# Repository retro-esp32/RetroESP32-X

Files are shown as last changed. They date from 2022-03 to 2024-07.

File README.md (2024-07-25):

# Introducing the Retro ESP32 *X*

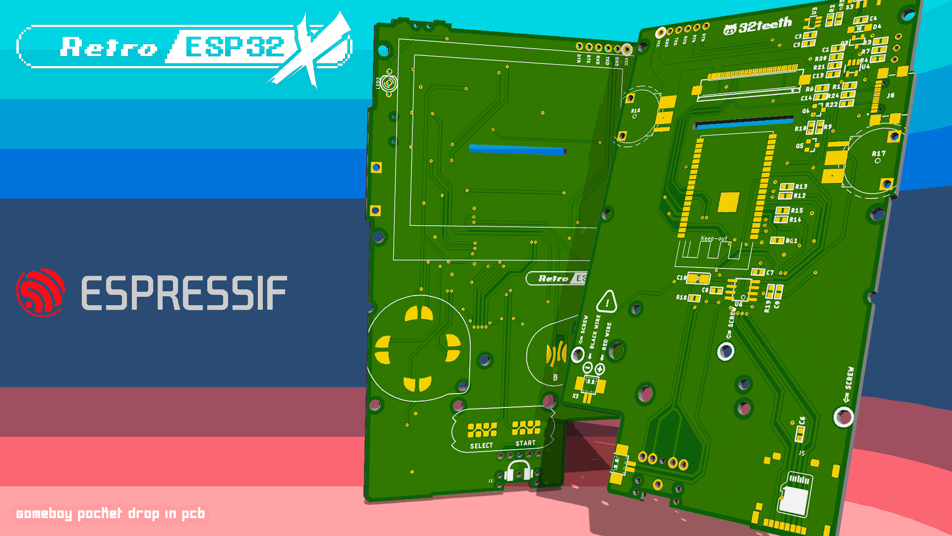
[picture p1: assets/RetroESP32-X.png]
Retro ESP32

> Gameboy Pocket Drop In PCB

We're thrilled to unveil the latest and greatest iteration of our beloved Retro ESP32 - the Retro ESP32 X! 🚀🕹️

**Retro ESP32 X** is certified unde Open Source Hardware as OSHWA UID [CA000030](https://certification.oshwa.org/ca000030.html) with CC-BY-SA-4.0 licensing

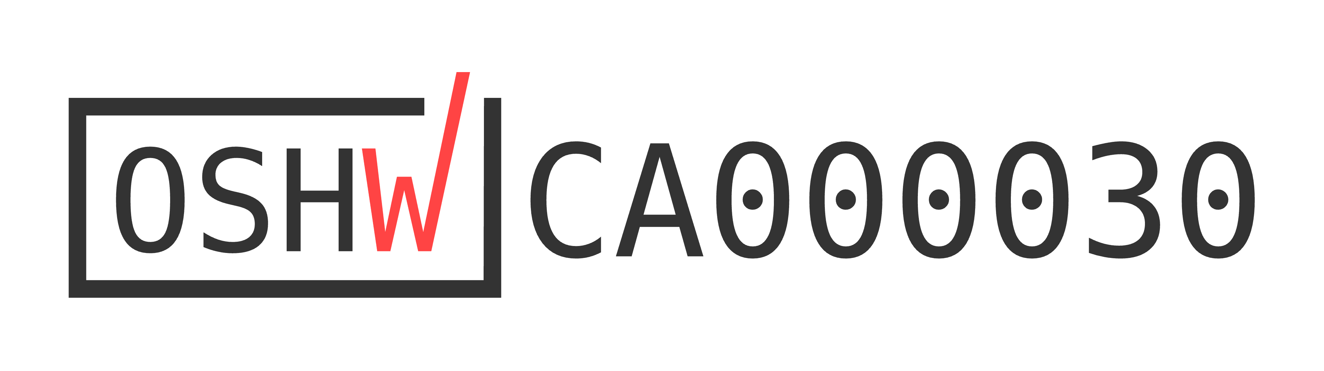
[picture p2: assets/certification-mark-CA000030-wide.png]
Open Source


## What's Public

- [x] PCB
- [x] Schematic
- [x] BOM
- [x] Gerber
- [x] DXF

## Updated Features

- [x] 2.6" ILI9342C SPI ISP
- [x] FPC Ribbon Connector
- [x] USB C (Charge Only)
- [x] Serial Pin Breakout

## Images

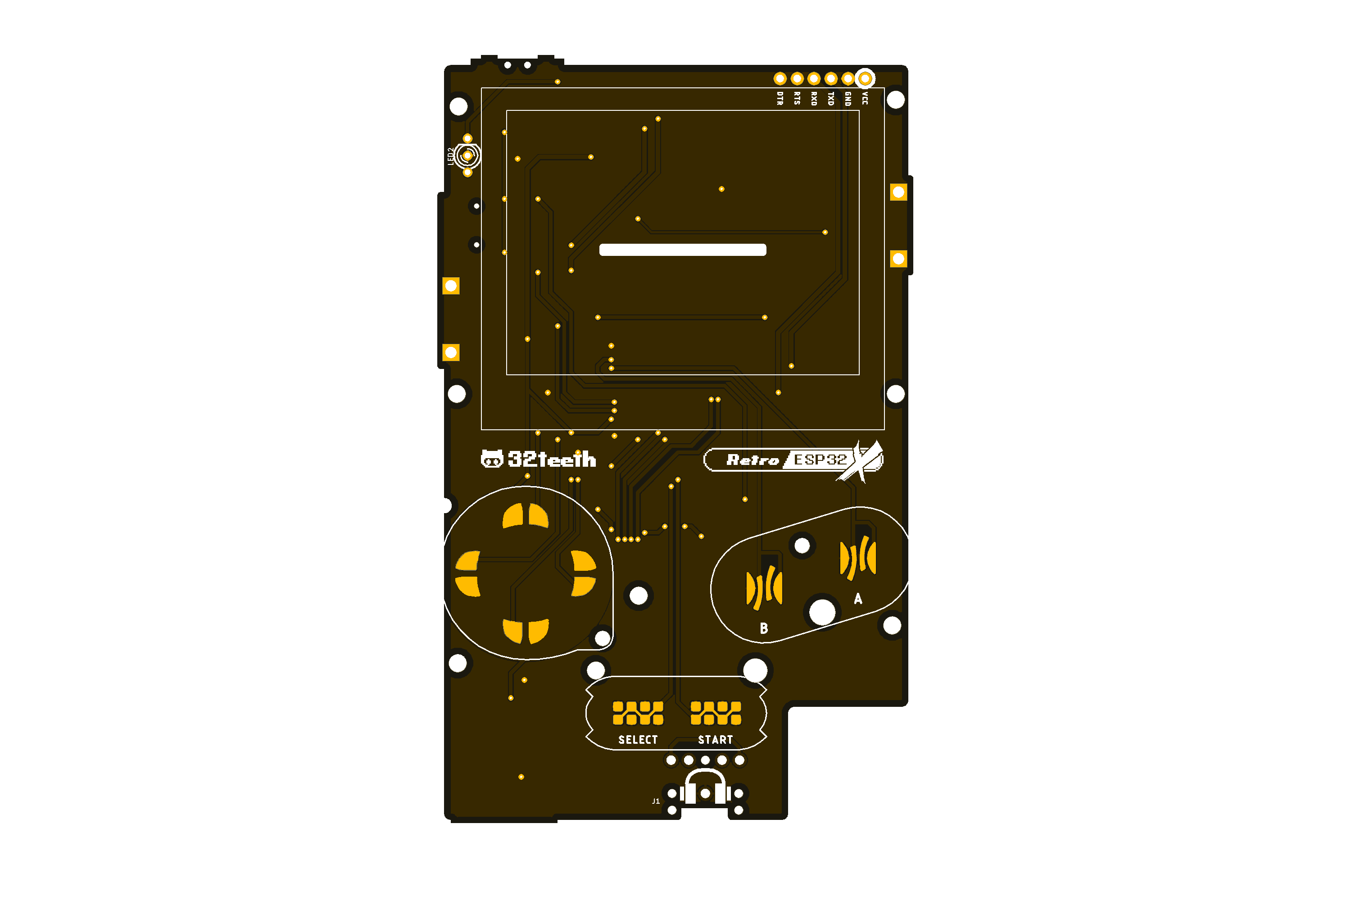
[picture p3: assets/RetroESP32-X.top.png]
Retro ESP32
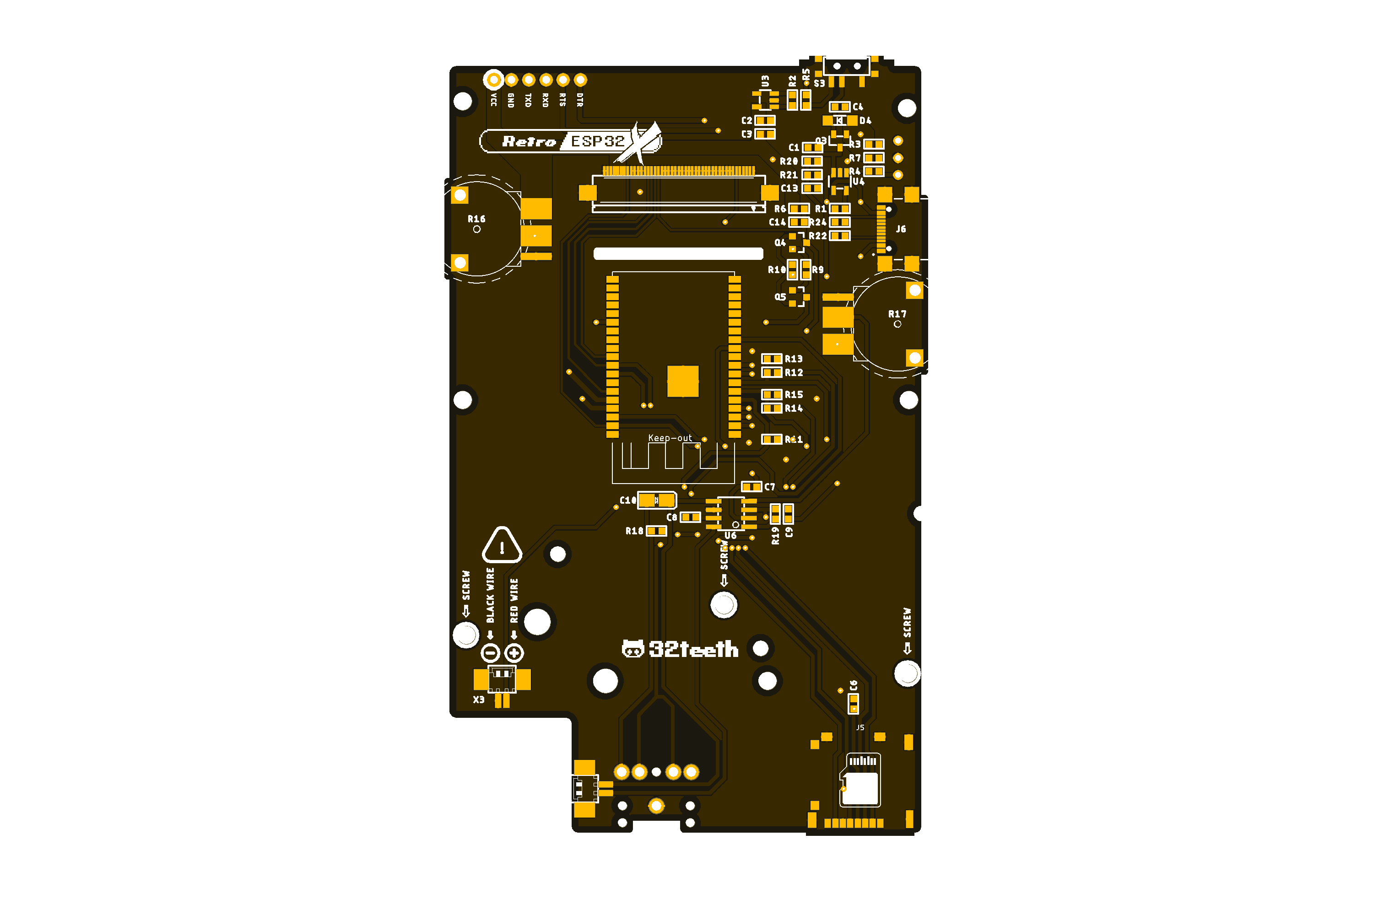
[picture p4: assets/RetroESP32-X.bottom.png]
Retro ESP32
|   |  |
| ---- | --- |
| Top  | Bottom |

## Authors

* **Eugene Yevhen Andruszczenko** - *Initial and Ongoing Work* - [32teeth](https://github.com/32teeth)

### License

This project is licensed under the Creative Commons Attribution Share Alike 4.0 International - see the [LICENSE.md](LICENSE.md) file for details

## Support
> Although we do this for 💕 of 🕹️<br/>
> **We Also Like Coffee!** <br/>
> *Please Consider Supporting* <br/>

Did you know, you can support us in a few way? We offer multiple sposorship tiers, with different rewards!

Take a *look*.
See what *fits*.

 Support (https://github.com/sponsors/retro-esp32)

**Thank You**

-----

**📢 Important Update:**
Please note that the original Retro ESP32 is now deprecated and is no longer supported. But fret not, because the all-new Retro ESP32 X is here to take your gaming experience to new heights! 📈✨

***The Retro ESP32 X uses the firmware from [Ducalex - Retro Go](https://github.com/ducalex/retro-go)***

Link to the Origina Rettro ESP32 Firmware Repo: [Check it out here!](https://github.com/retro-esp32/RetroESP32)

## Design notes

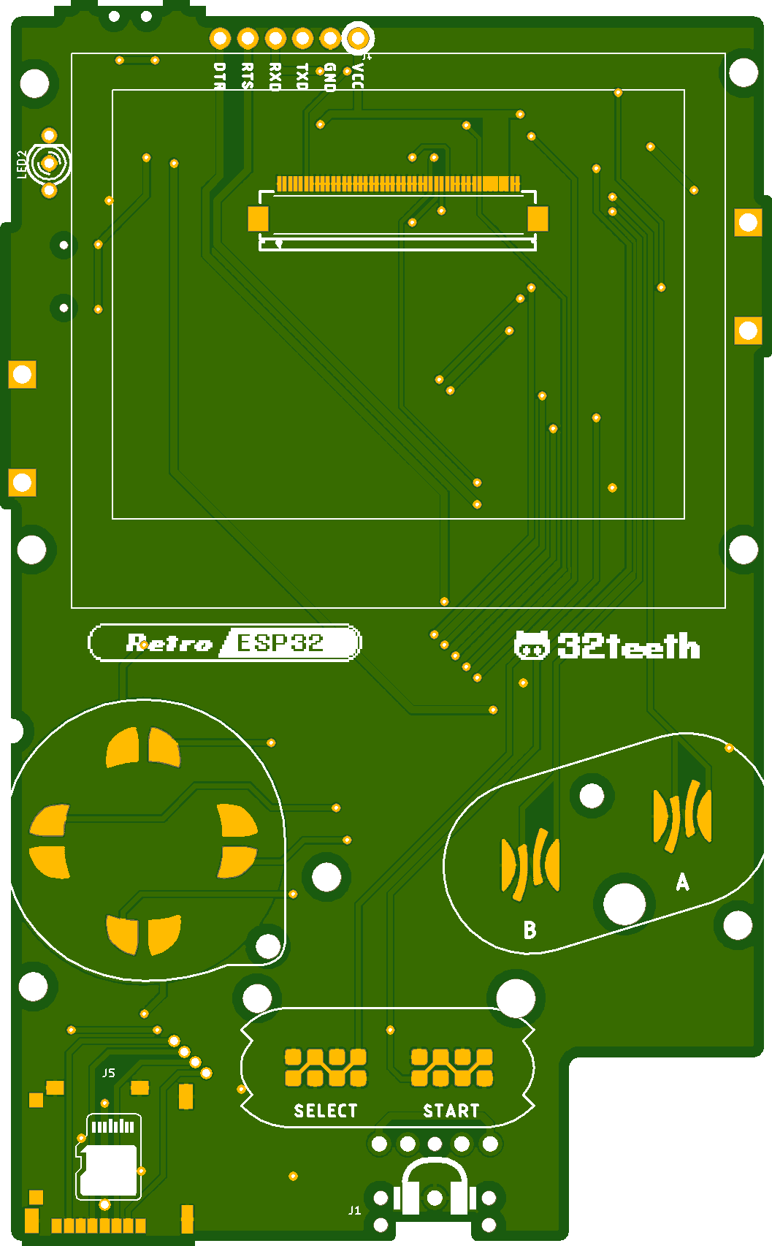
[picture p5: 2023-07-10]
assets/RetroESP32.serial.top.png

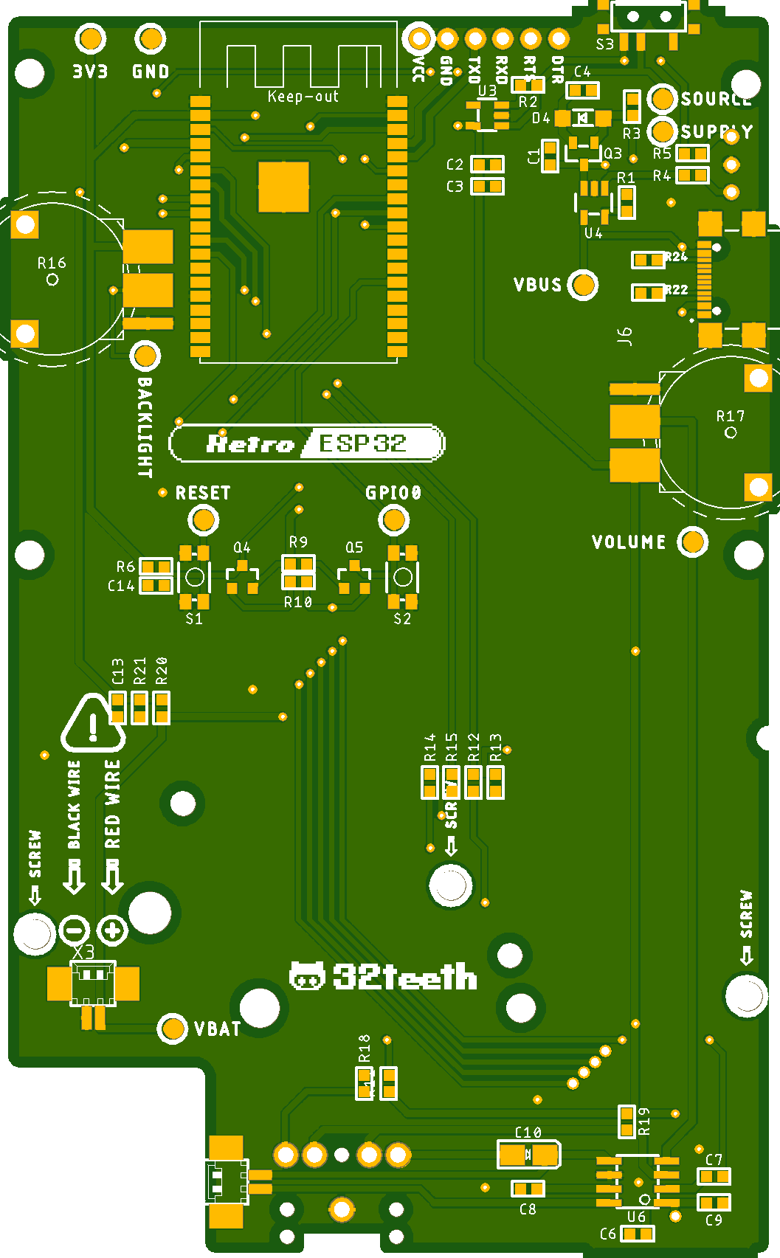
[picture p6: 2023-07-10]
assets/RetroESP32.serial.bottom.png

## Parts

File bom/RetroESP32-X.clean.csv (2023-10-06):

Qty | Parts | Value | MPN | Package | Device
1 | J4 |  |  | 1X06_NO_SILK | CONN_06NO_SILK_NO_POP
1 | R7 | 0 | ERJ-3GEY0R00V | 0603-MINI | RESISTOR0603MINI
1 | C13 | 0.1uF | CL10B104KB8NNNC | 0603-MINI-CAP | CAP_CERAMIC
5 | R2, R3, R19, R20, R21 | 100K | ERJ-PA3J104V | 0603-MINI | RESISTOR0603MINI
1 | C10 | 100uF | F930J107KAA | EIA3216-18/A-W | CAP_TANTALUMA/3216_WAVE
8 | R6, R9, R10, R11, R12, R13, R14, R15 | 10K | ERJ-PA3J103V | 0603-MINI | RESISTOR0603MINI
4 | C1, C2, C4, C6 | 10uF | CL10A106MP8NNNC | 0603-MINI-CAP | CAP_CERAMIC
1 | R18 | 150 Ohm | ERJ-PA3J151V | 0603-MINI | RESISTOR0603MINI
2 | R1, R5 | 1K | ERJ-PA3J102V | 0603-MINI | RESISTOR0603MINI
4 | C3, C8, C9, C14 | 1uF | CL10A105KP8NNNC | 0603-MINI-CAP | CAP_CERAMIC
1 | C7 | 220pF | CL10C221JB8NNNC | 0603-MINI-CAP | CAP_CERAMIC
2 | R16, R17 | 27k |  | THUMBWHEEL | THUMBWHEEL
1 | R4 | 470 | ERJ-PA3J471V | 0603-MINI | RESISTOR0603MINI
2 | R22, R24 | 5.1K | ERJ-PA3F5101V | 0603-MINI | RESISTOR0603MINI
1 | J5 | 503182-1852_503182-1852 | 5031821852 | 503182-1852_MOLEX_503182-1852 | 503182-1852_503182-1852
2 | X2, X3 | 53261-02 | 532614002 | 53261-02 | 53261-02
1 | J1 | AUDIO_JACK_3.5MM_KIT | SJ1-3525NG-GR | AUDIO-JACK-KIT | AUDIO_JACK_3.5MM_KIT
2 | SELECT, START | BUTTON_START+SELECT |  | START+SELECT-STANDARD | BUTTON_START+SELECT
1 | Q3 | DMG3415U-7 | DMG3415U-7 | SOT23-R | MOSFET-P
1 | U1 | ESP32-WROVER | ESP32-WROVER (16MB) | ESP32-WROVER_ESP32-WROVER | ESP32-WROVER
1 | U$11 |  | 541044531
1 | LED2 | LED_L-115WEGW-CA | SSL-LX3059IGW | LED_DUOLED-A-3MM | LED_L-115WEGW-CA
1 | U6 | LM4875 | LM4875MX/NOPB | SOIC8 | LM4875
1 | D4 | MBR120 | MBR120LSFT1G | SOD-123 | DIODE-SCHOTTKYSOD-123
1 | U4 | MCP73832T-2ACI/OT | MCP73832T-2ACI/OT | SOT23-5-1 | MCP73831/2
1 | S3 | POWER-SWITCH | MA12RTR | RETIRED_KPS-1290 | POWER-SWITCH
1 | J6 | USB4110-GF-A_REVB | USB4110-GF-A | GCT_USB4110-GF-A_REVB | USB4110-GF-A_REVB
1 | U3 | XC6210B332MR-G | XC6210B332MR-G | SOT23-5 | AP2112-3.3
2 | Q4, Q5 | mmbt2222 | MMBT2222A-7-F | SOT23-3 | TRANSISTOR_NPNSOT23-3

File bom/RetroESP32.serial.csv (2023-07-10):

Qty | Designator | MPN | Purchase Link
1 | J1 | SJ1-3525NG-GR | https://www.digikey.com/en/products/detail/cui-devices/SJ1-3525NG-GR/2295990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
1 | C13 | CL10B104KB8NNNC | https://www.digikey.com/en/products/detail/samsung-electro-mechanics/CL10B104KB8NNNC/3886658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
4 | C1, C2, C4, C6 | CL10A106MP8NNNC | https://www.digikey.com/en/products/detail/samsung-electro-mechanics/CL10A106MP8NNNC/3887529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
4 | C3, C8, C9, C14 | CL10A105KP8NNNC | https://www.digikey.com/en/products/detail/samsung-electro-mechanics/CL10A105KP8NNNC/3886840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
1 | C7 | CL10C221JB8NNNC | https://www.digikey.com/en/products/detail/samsung-electro-mechanics/CL10C221JB8NNNC/3886706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
1 | J5 | 5031821852 | https://www.digikey.com/en/products/detail/molex/5031821852/4693482?s=N4IgTCBcDaIKwAYDMBGAHGdcIF0C%2BQA
1 | J6 | USB4110-GF-A | https://www.digikey.com/en/products/detail/gct/USB4110-GF-A/10384547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
1 | U4 | MCP73832T-2ACI/OT | https://www.digikey.com/en/products/detail/microchip-technology/MCP73832T-2ACI-OT/1223142
2 | S1, S2 | KMR221GLFS | https://www.digikey.com/en/products/detail/c-k/KMR221GLFS/550472?s=N4IgTCBcDaINIFkBKYwEYDiAZAYgZRAF0BfIA
1 | Q3 | DMG3415U-7 | https://www.digikey.com/en/products/detail/diodes-incorporated/DMG3415U-7/2052768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
2 | R1, R5 | ERJ-PA3J152V | https://www.digikey.com/en/products/detail/panasonic-electronic-components/ERJ-PA3J152V/5035991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
5 | R2, R3, R19, R20, R21 | ERJ-PA3J104V | https://www.digikey.com/en/products/detail/panasonic-electronic-components/ERJ-PA3J104V/5035972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
8 | R6, R9, R10, R11, R12, R13, R14, R15 | ERJ-PA3J103V | https://www.digikey.com/en/products/detail/panasonic-electronic-components/ERJ-PA3J103V/5035971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
1 | R18 | ERJ-PA3J151V | https://www.digikey.com/en/products/detail/panasonic-electronic-components/ERJ-PA3J151V/5035990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
1 | R4 | ERJ-PA3J471V | https://www.digikey.com/en/products/detail/panasonic-electronic-components/ERJ-PA3J471V/5036065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
2 | R22, R24 | ERJ-PA3F5101V | https://www.digikey.com/en/products/detail/panasonic-electronic-components/ERJ-PA3F5101V/5035934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
1 | U3 | XC6210B332MR-G | https://www.digikey.com/en/products/detail/torex-semiconductor-ltd/XC6210B332MR-G/2138119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
1 | S3 | MA12RTR | https://www.digikey.com/en/products/detail/apem-inc/MA12RTR/1795601?s=N4IgTCBcDaILIEECMYBKAVVIC6BfIA
1 | LED2 | SSL-LX3059IGW | https://www.digikey.com/en/products/detail/lumex-opto-components-inc/SSL-LX3059IGW/242268
1 | C10 | F930J107KAA | https://www.digikey.com/en/products/detail/kyocera-avx/F930J107KAA/4005275
2 | Q4, Q5 | MMBT2222A-7-F | https://www.digikey.com/en/products/detail/diodes-incorporated/MMBT2222A-7-F/814503
1 | U1 | ESP32-WROVER (16MB) | https://www.digikey.com/en/products/filter/rf-transceiver-modules-and-modems/872
1 | U$11 | 541324562 | https://www.digikey.com/en/products/detail/molex/0541324562/3197010
1 | U6 | LM4875MX/NOPB | https://www.digikey.com/en/products/detail/texas-instruments/LM4875MX-NOPB/1871686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
1 | D4 | MBR120LSFT1G | https://www.digikey.com/en/products/detail/onsemi/MBR120LSFT1G/1748986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
2 | X2, X3 | 53261-02 | 0532614002 | https://www.digikey.ca/en/products/detail/molex/0532614002/15622958
1 | N/A - This is the LCD itself | ET026LQTM008 | https://www.alibaba.com/product-detail/Support-Small-Quantity-2-6-inch_1600609986142.htmlgit

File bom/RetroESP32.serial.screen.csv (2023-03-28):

Qty | Designator | MPN | Purchase Link
1 | U$11 | 541324562 | https://www.digikey.com/en/products/detail/molex/0541324562/3197010

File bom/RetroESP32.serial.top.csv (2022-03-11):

Qty | Designator | MPN | Purchase Link
1 | J5 | 5031821852 | https://www.digikey.com/en/products/detail/molex/5031821852/4693482?s=N4IgTCBcDaIKwAYDMBGAHGdcIF0C%2BQA
1 | U$11 | 541324562 | https://www.digikey.com/en/products/detail/molex/0541324562/3197010

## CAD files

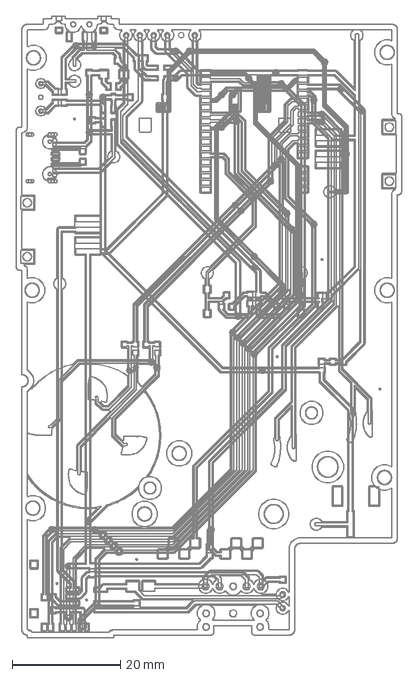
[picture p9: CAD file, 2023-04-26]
dxf/RetroESP32.serial 2.dxf
71.2 x 115.0 mm

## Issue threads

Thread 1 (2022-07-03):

Will there be any issue if using ili9341 display driver insted of ili9342?

rohitsam, 2022-07-03:
I want to work on this project, but am unable to find ili9342-based displays here in India.
I found a couple of displays that are
[ili9341 based](https://robu.in/product/2-2-inch-240320-lcd-color-screen-tft-spi-serial-interface-module-compatible-with-5110/) could anyone please tell me if these can work?

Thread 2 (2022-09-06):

Charger chip

mikeinkl1, 2022-09-06:
Gren led doesnt come on. The issue is probably that
U4 should be MCP73831 not MCP73832.
Otherwise great little project.

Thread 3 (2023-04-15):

Thumbwheel link

advtechsol, 2023-04-15:
Do you have a link for the thumbwheel component?

32teeth, 2023-04-24:
This is the one we use
[Gameboy Pocket Pot Switch](https://www.aliexpress.us/item/3256804826762559.html?gatewayAdapt=glo2usa4itemAdapt&_randl_shipto=US)

I will add them to the BOM

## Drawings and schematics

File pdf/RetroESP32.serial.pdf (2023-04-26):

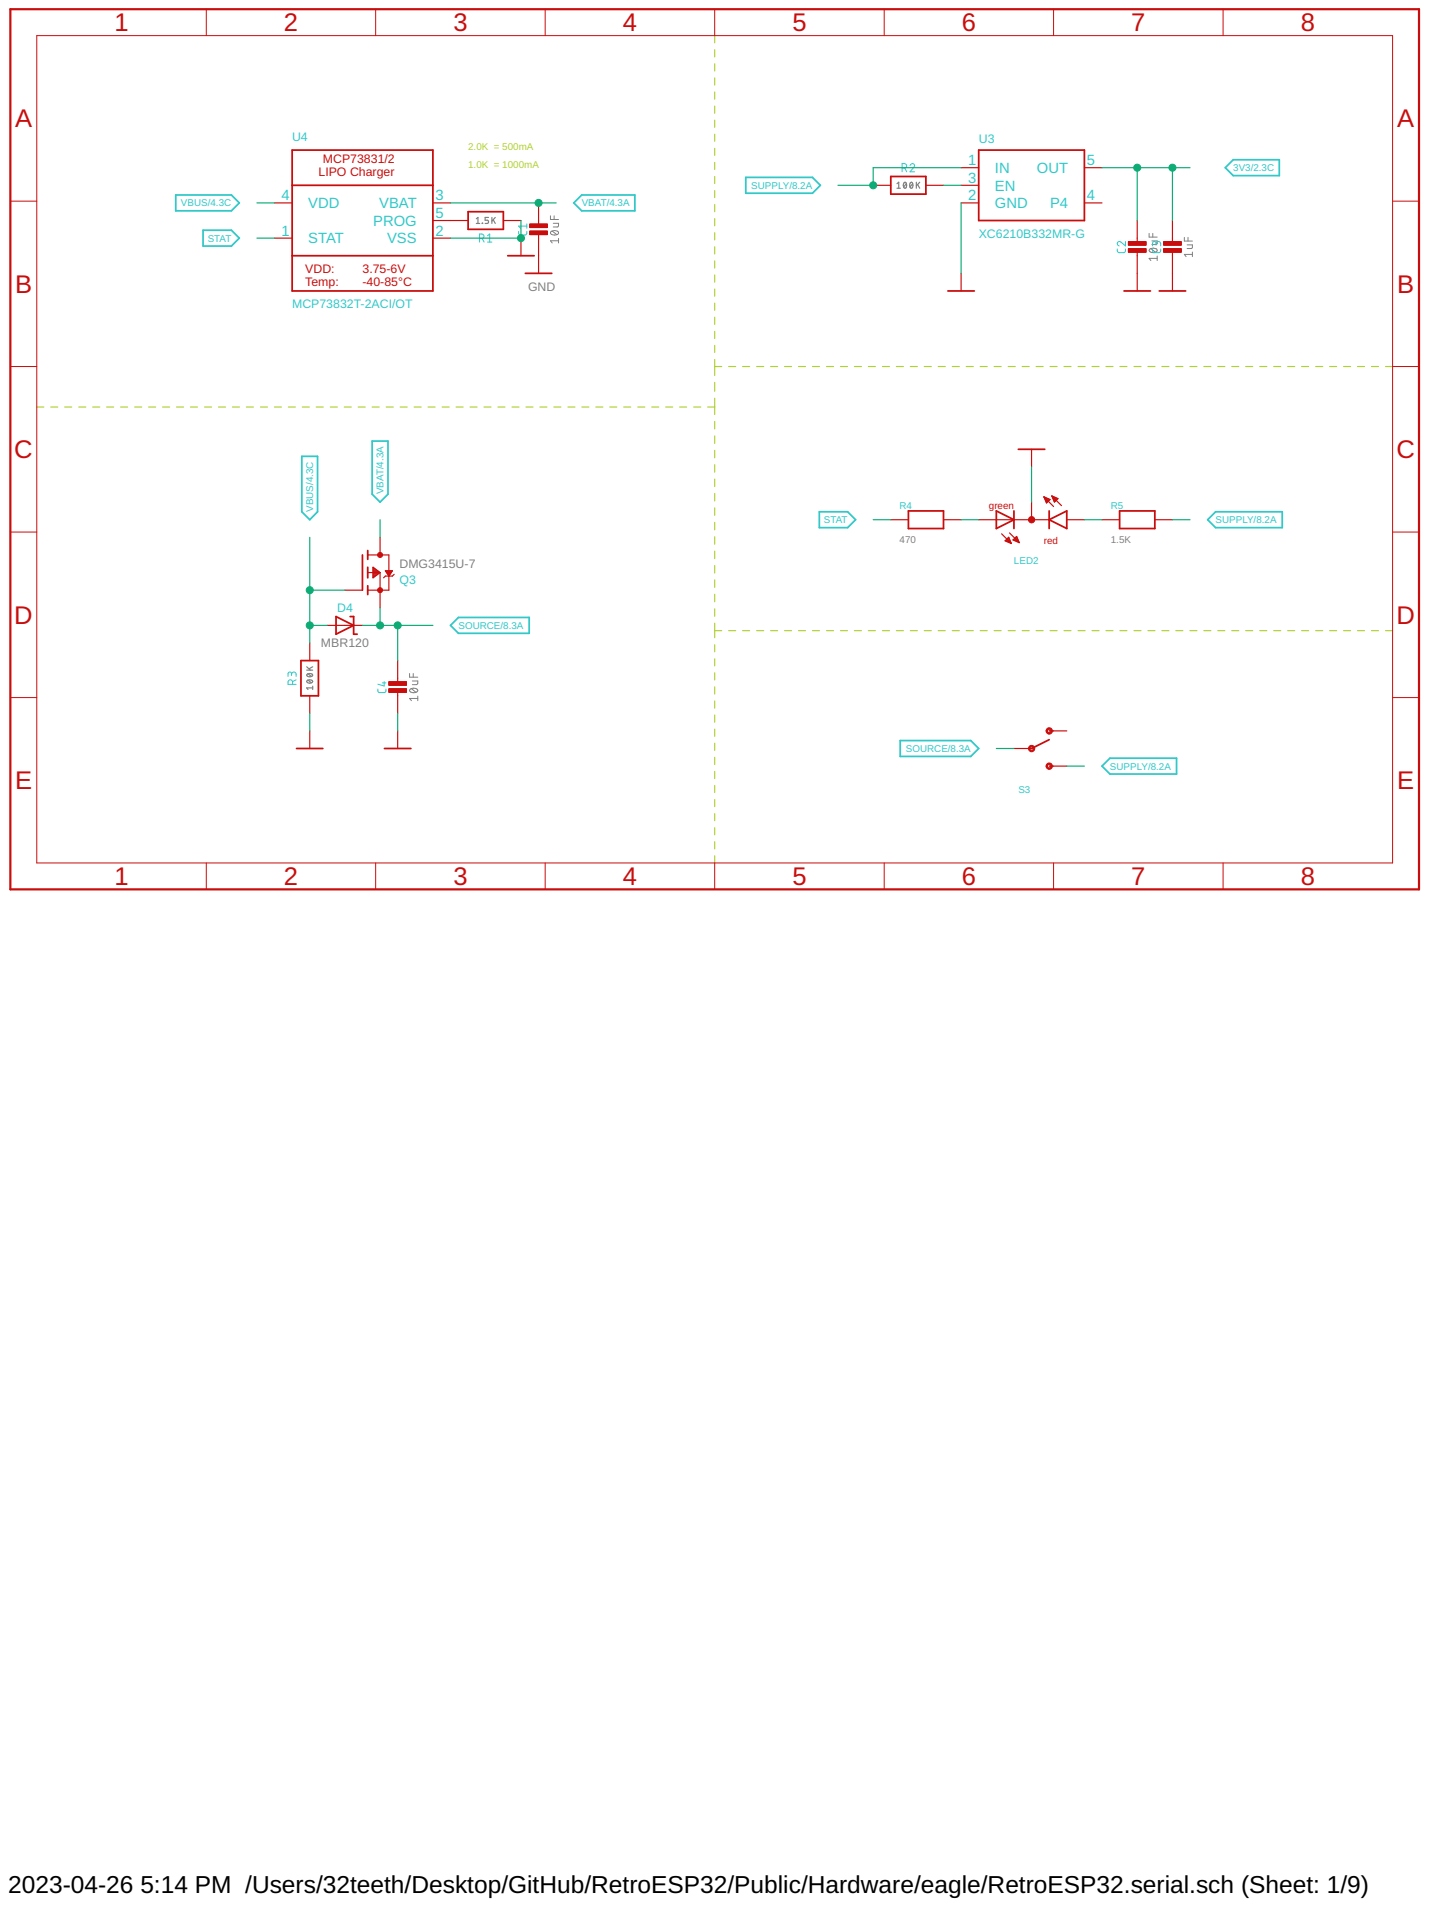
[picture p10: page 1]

2023-04-26 5:14 PM /Users/32teeth/Desktop/GitHub/RetroESP32/Public/Hardware/eagle/RetroESP32.serial.sch (Sheet: 1/9)

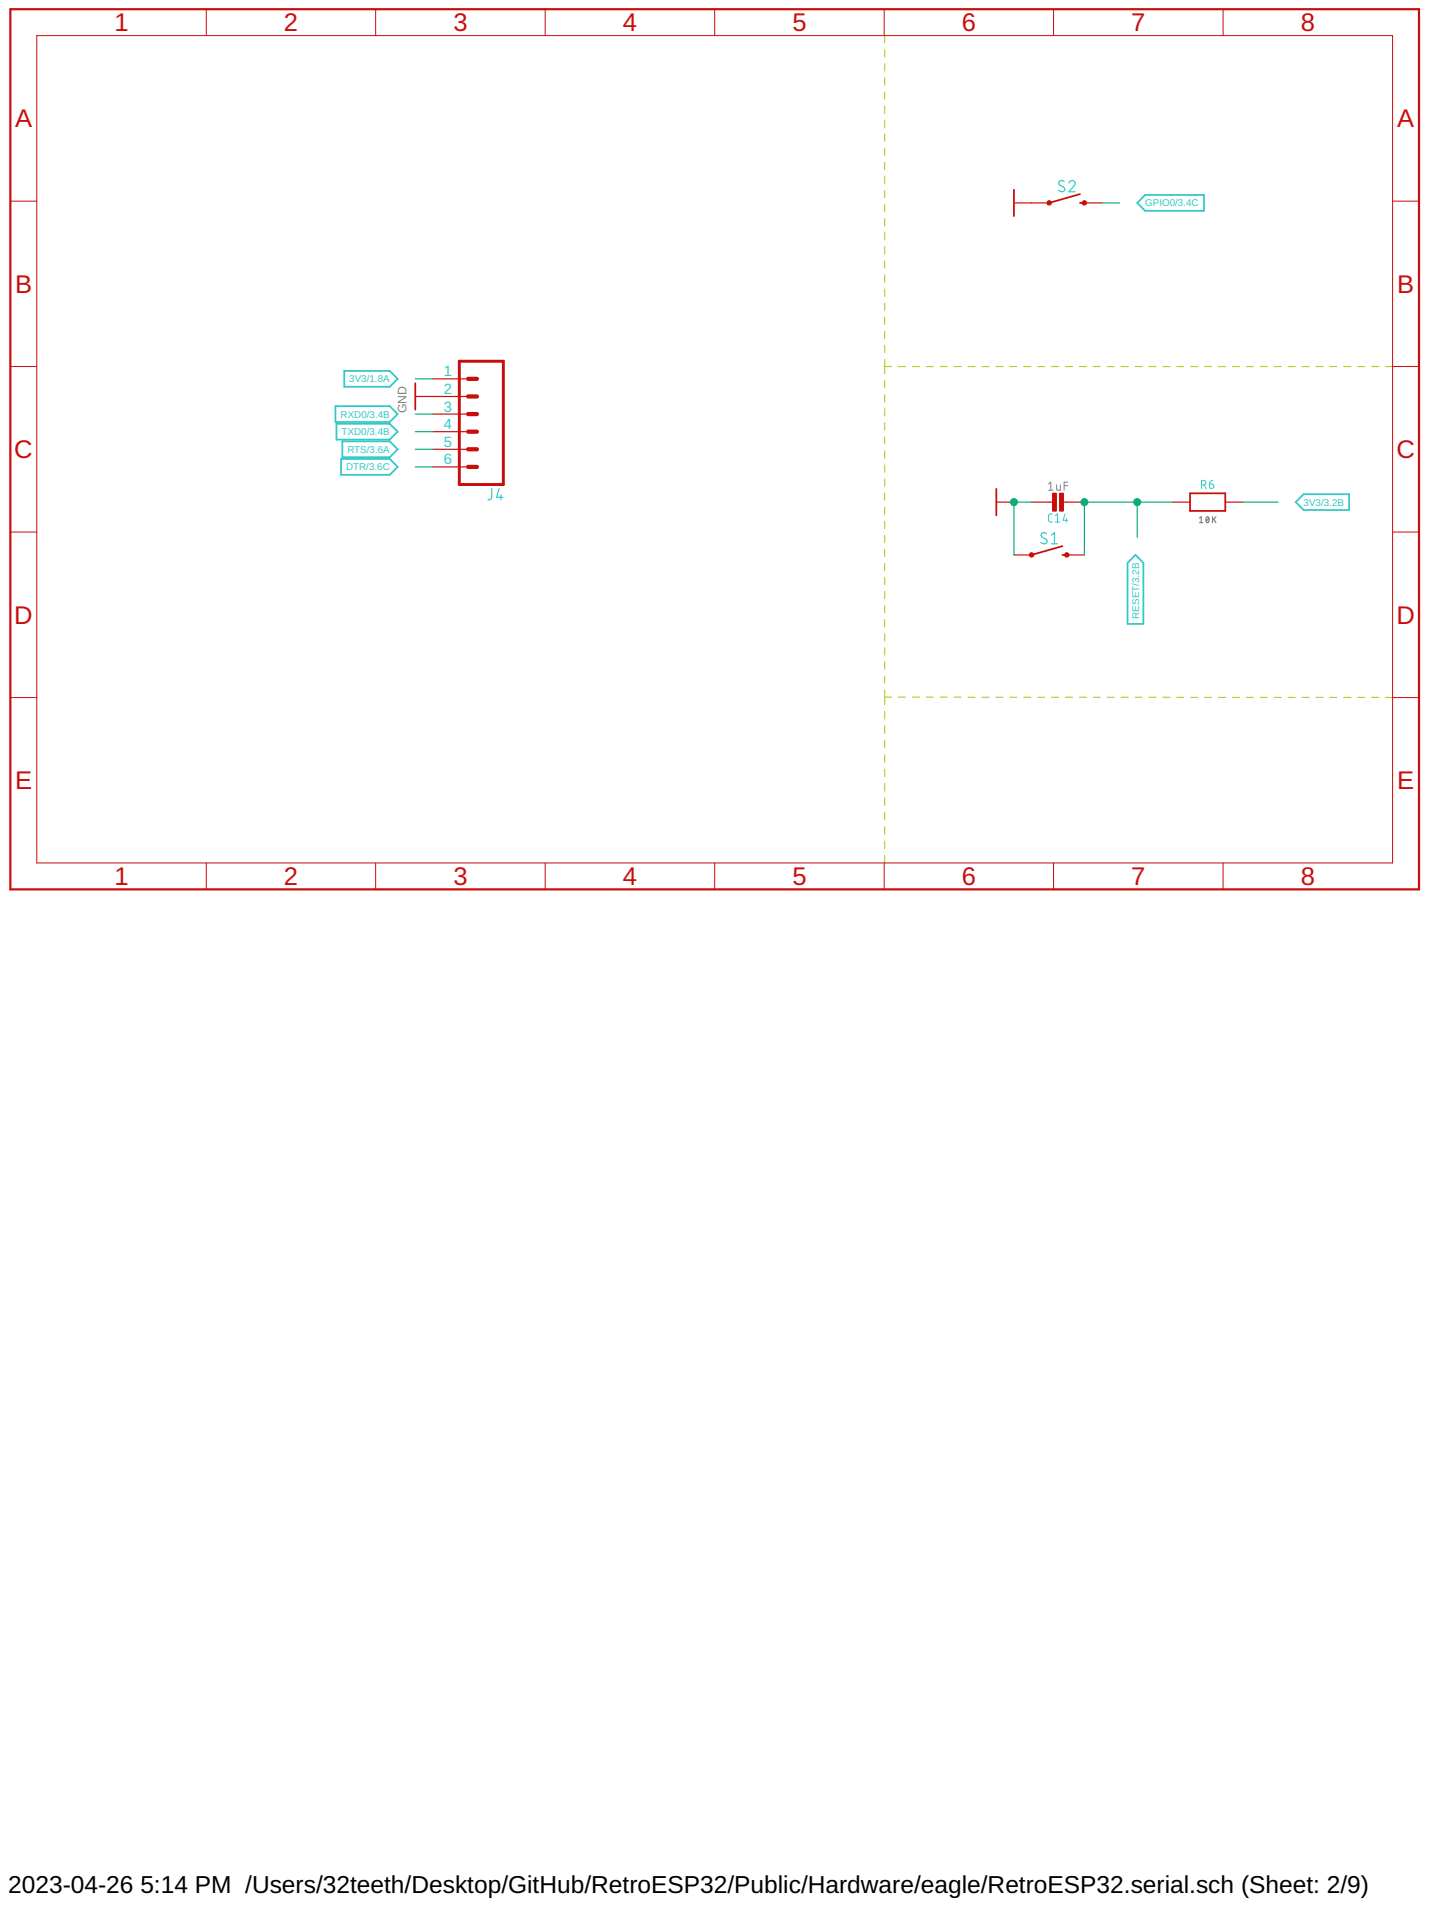
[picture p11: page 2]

2023-04-26 5:14 PM /Users/32teeth/Desktop/GitHub/RetroESP32/Public/Hardware/eagle/RetroESP32.serial.sch (Sheet: 2/9)

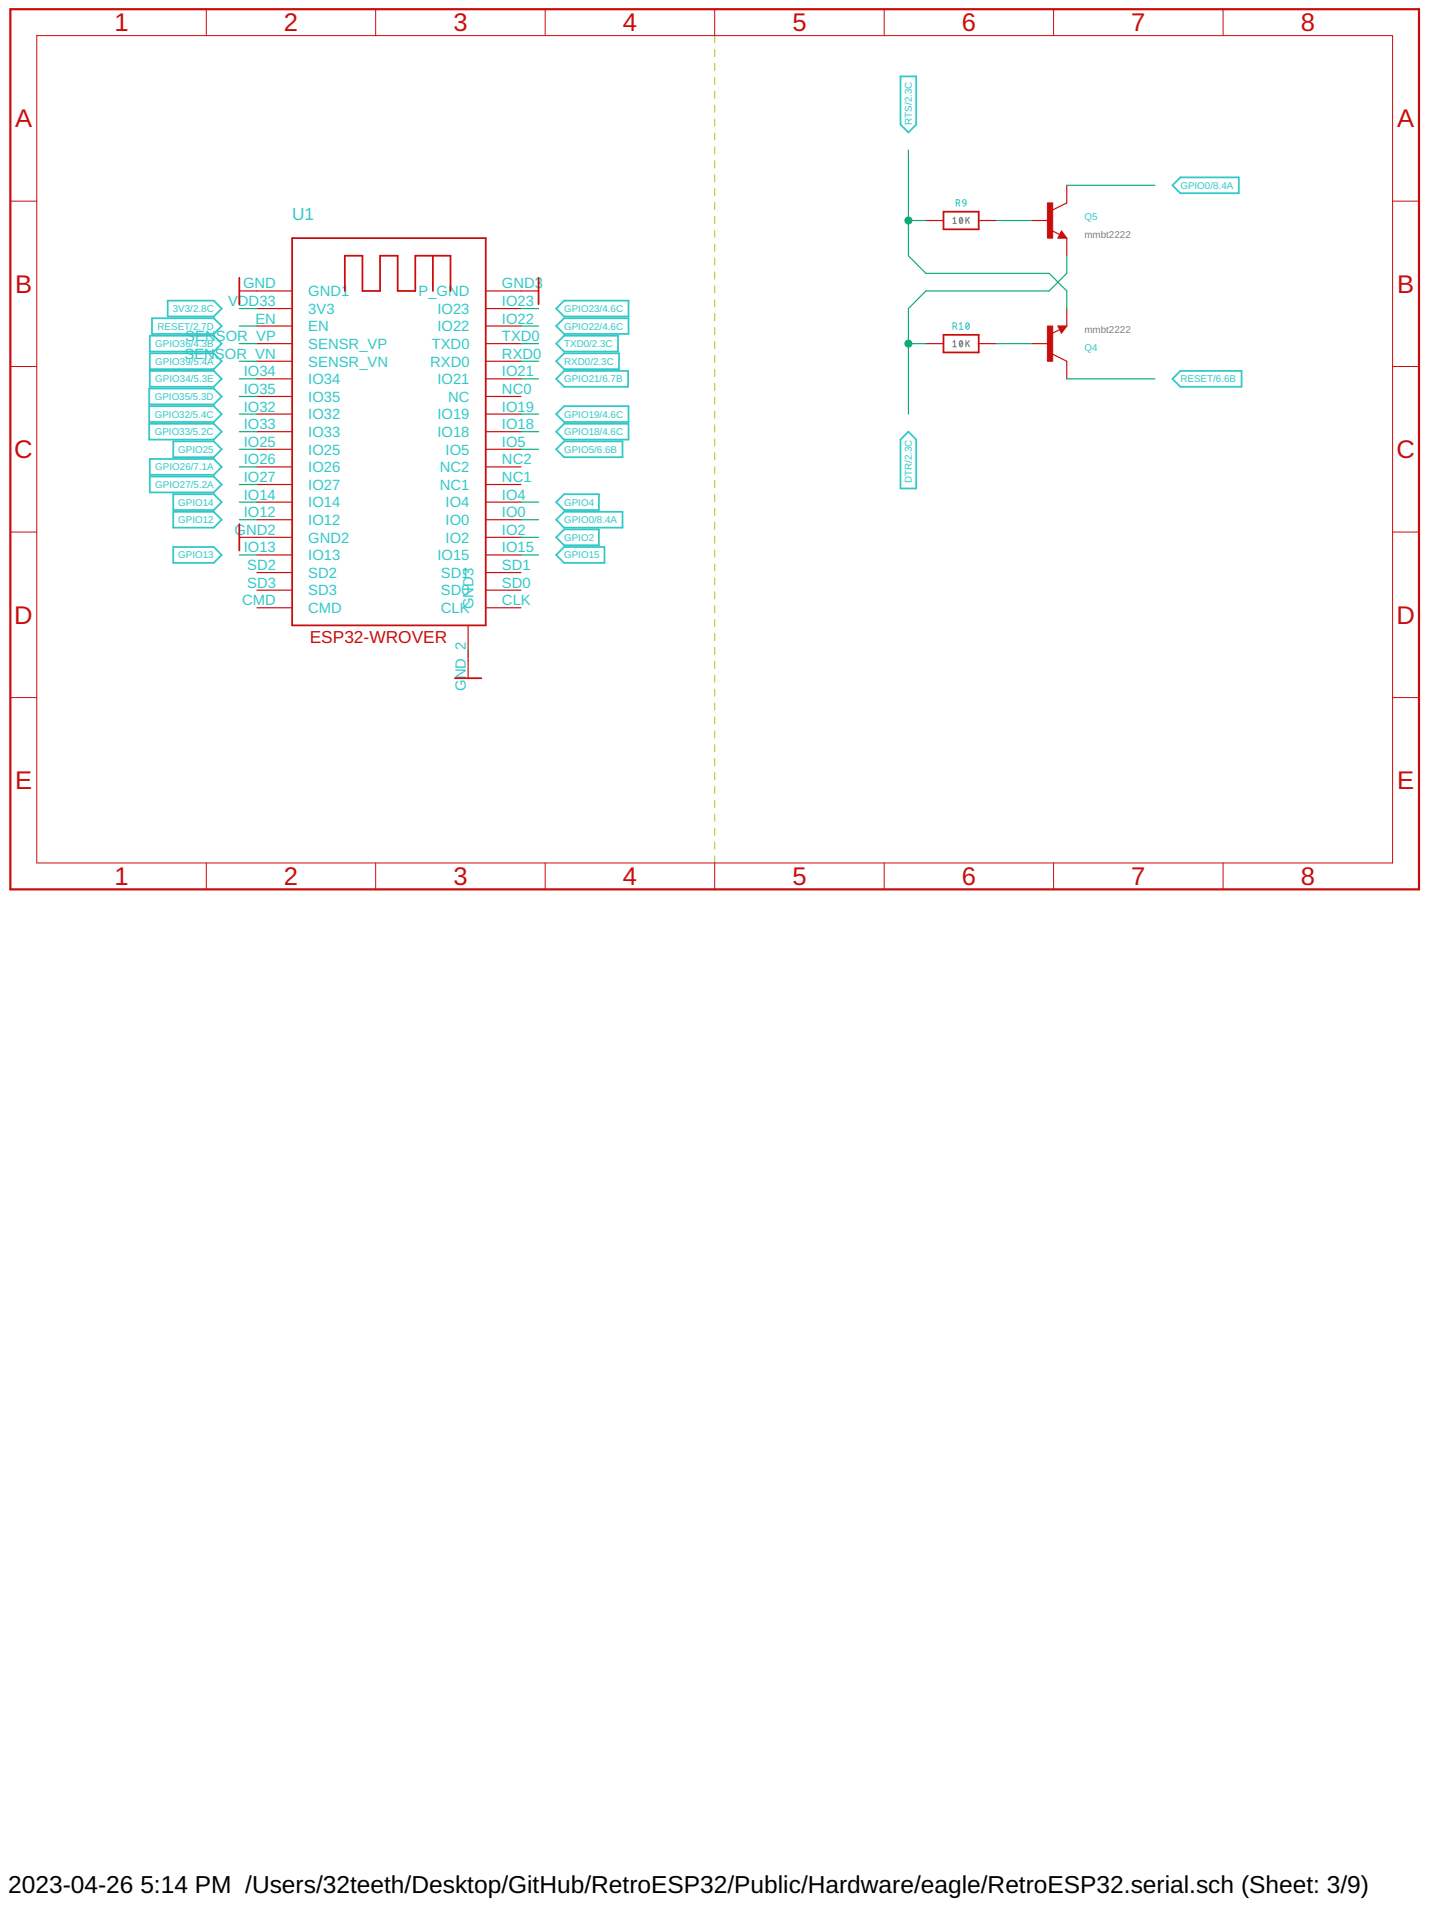
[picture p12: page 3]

2023-04-26 5:14 PM /Users/32teeth/Desktop/GitHub/RetroESP32/Public/Hardware/eagle/RetroESP32.serial.sch (Sheet: 3/9)

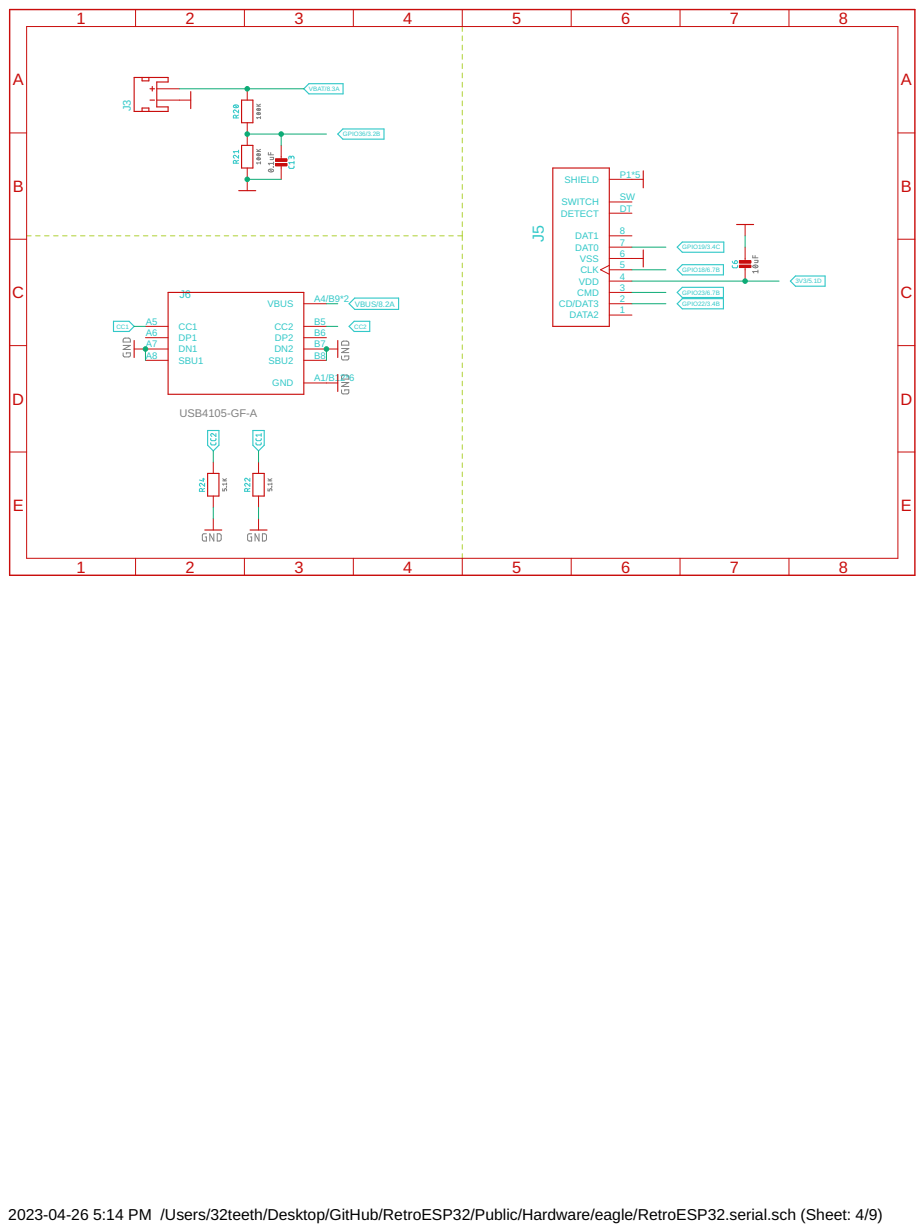
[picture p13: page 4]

2023-04-26 5:14 PM /Users/32teeth/Desktop/GitHub/RetroESP32/Public/Hardware/eagle/RetroESP32.serial.sch (Sheet: 4/9)

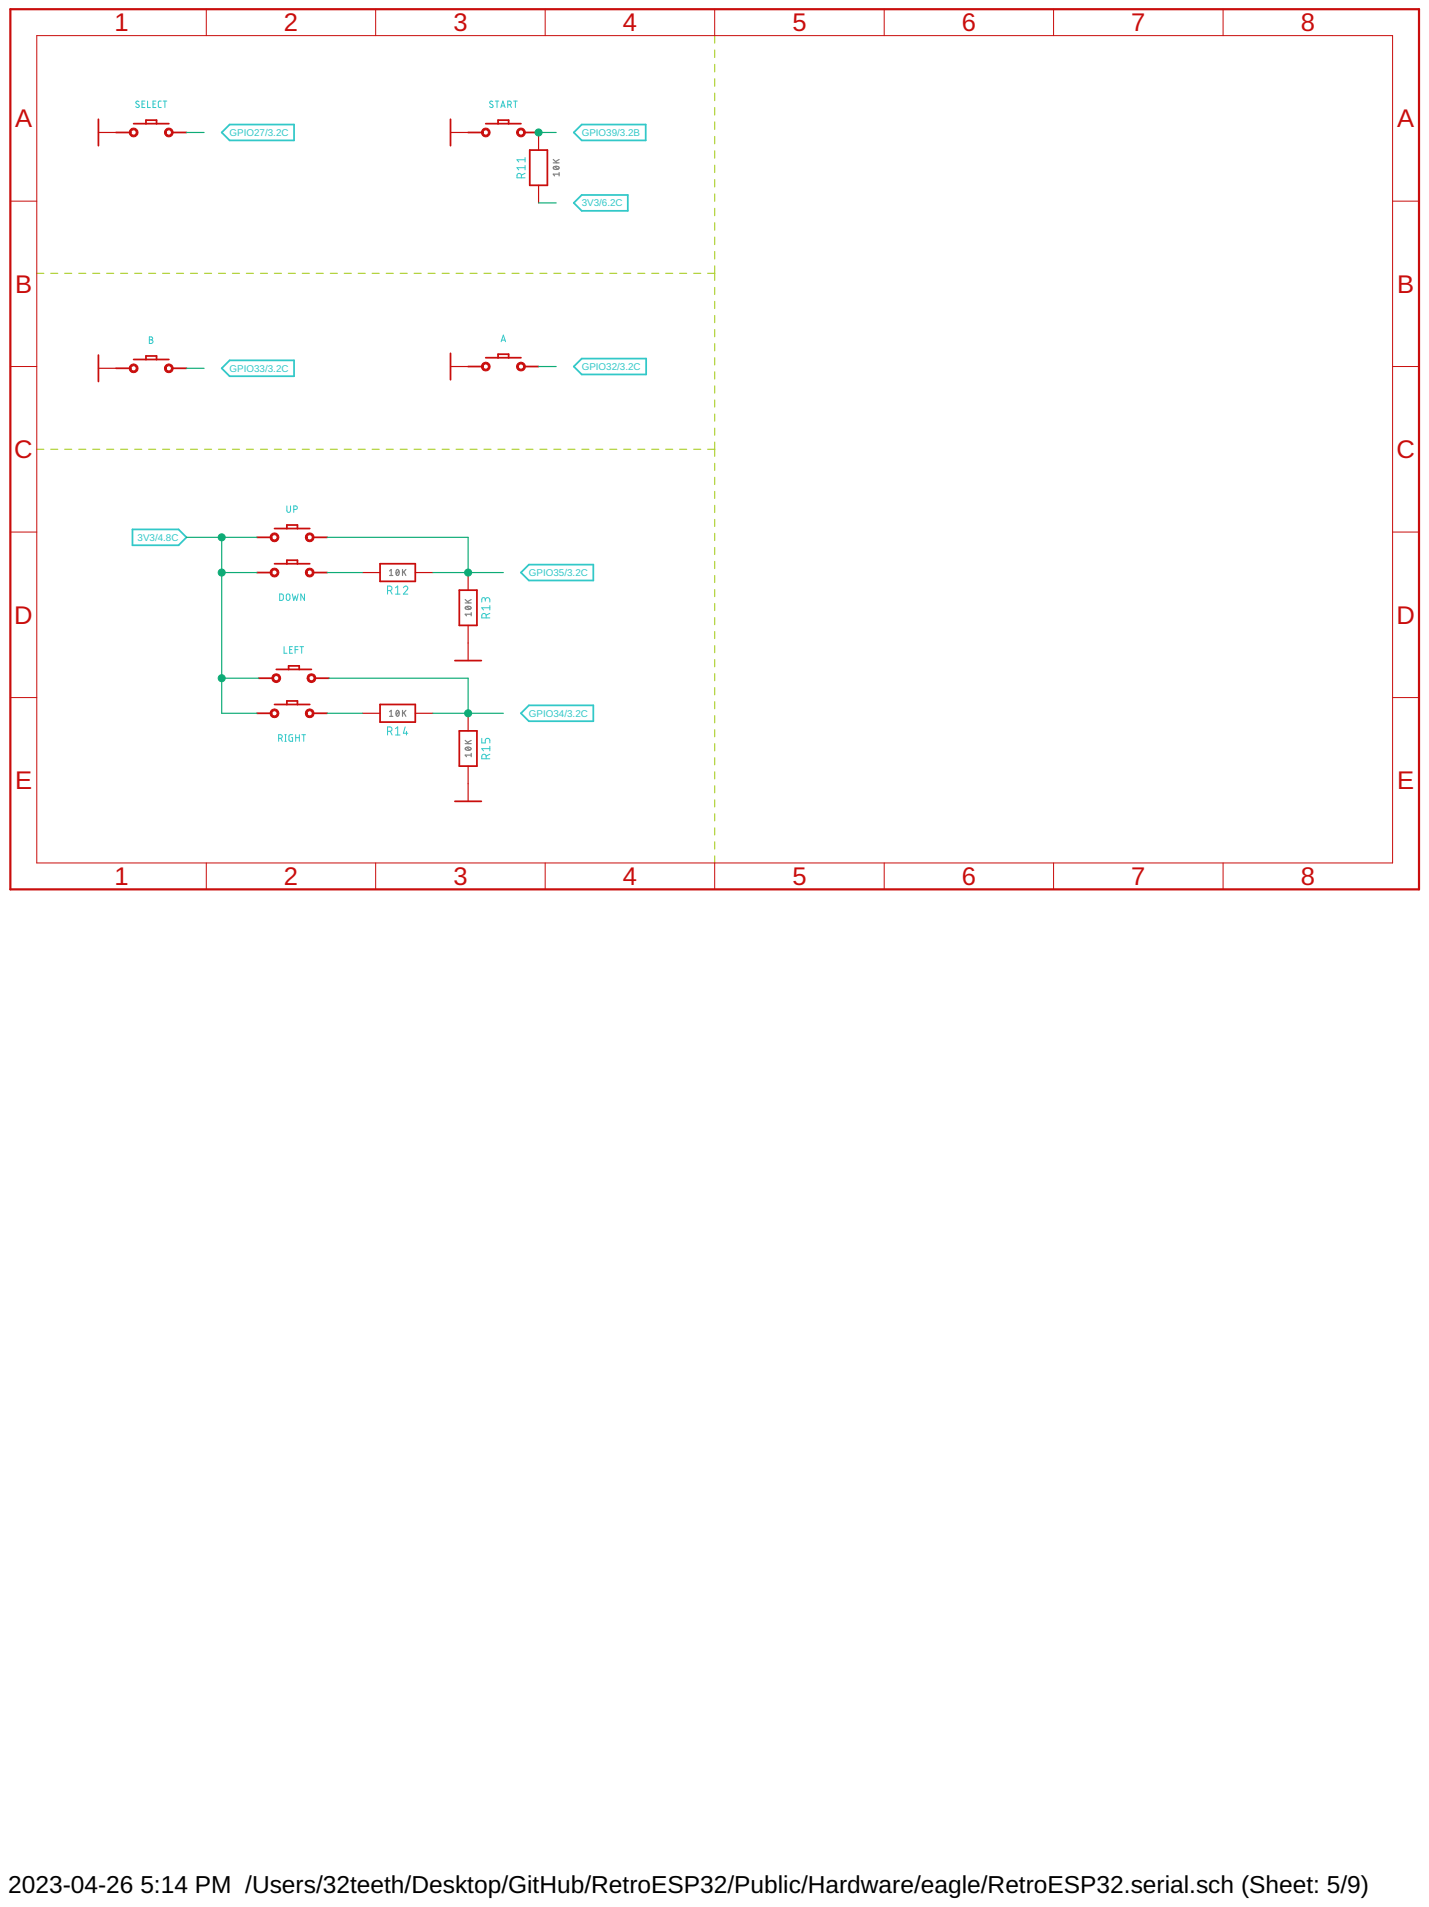
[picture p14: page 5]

2023-04-26 5:14 PM /Users/32teeth/Desktop/GitHub/RetroESP32/Public/Hardware/eagle/RetroESP32.serial.sch (Sheet: 5/9)

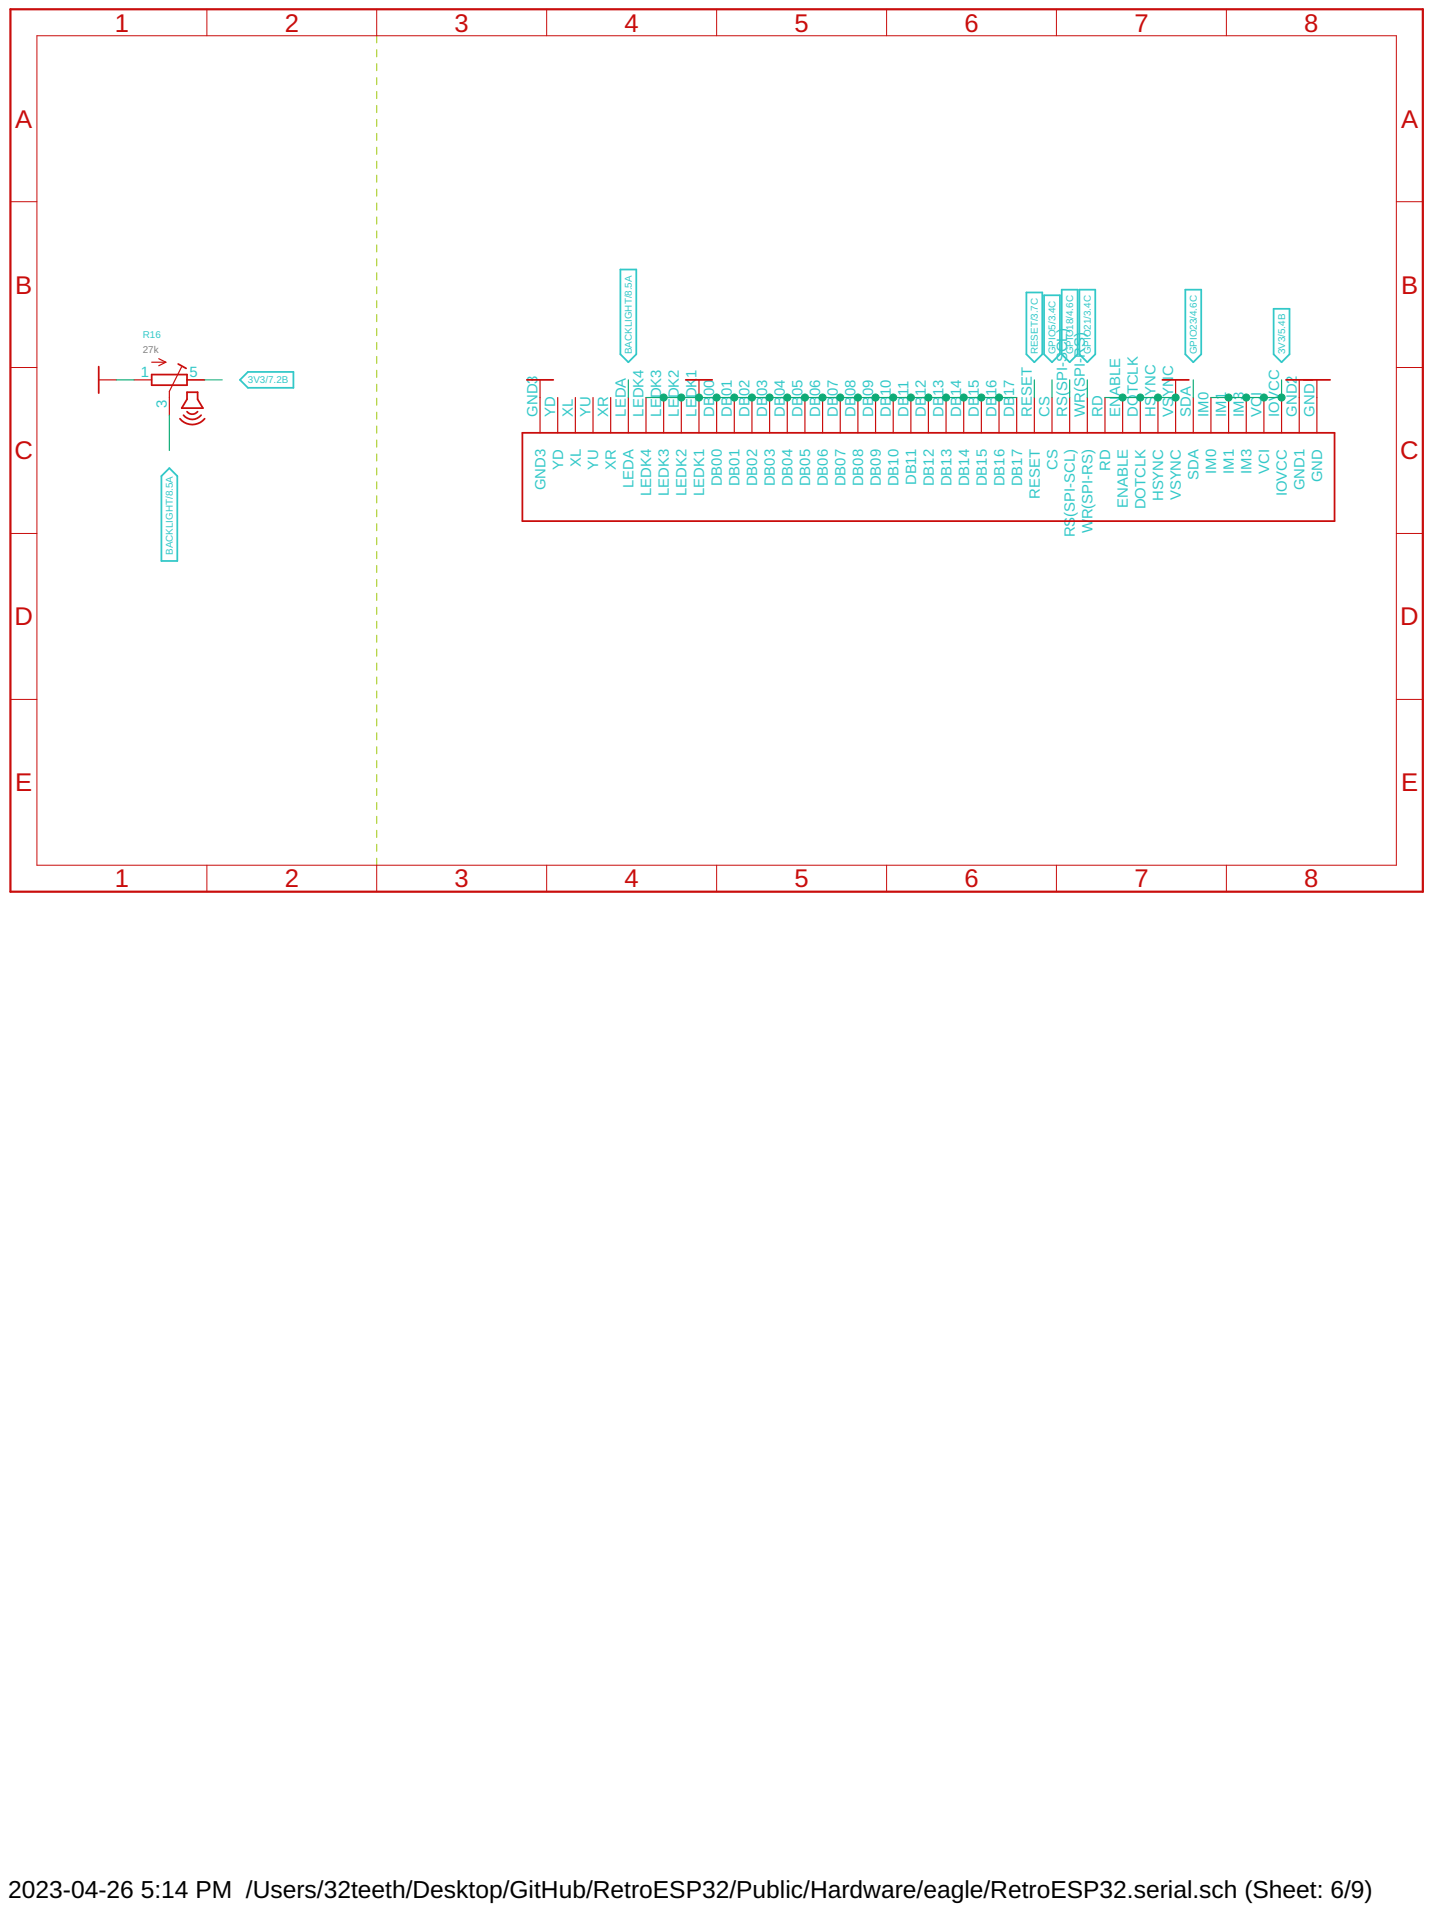
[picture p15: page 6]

RD WR(SPI-RS) WR(SPI-RS) RS(SPI-SCL) RS(SPI-SCL) CS CS RESET RESET DB17 DB17 DB16 DB16 DB15 DB15 DB14 DB14 DB13 DB13 DB12 DB12 DB11 DB11 DB10 DB10 DB09 DB09 DB08 DB08 DB07 DB07 DB06 DB06 DB05 DB05 DB04 DB04 DB03 DB03 DB02 DB02 DB01 DB01 DB00 DB00

2023-04-26 5:14 PM /Users/32teeth/Desktop/GitHub/RetroESP32/Public/Hardware/eagle/RetroESP32.serial.sch (Sheet: 6/9)

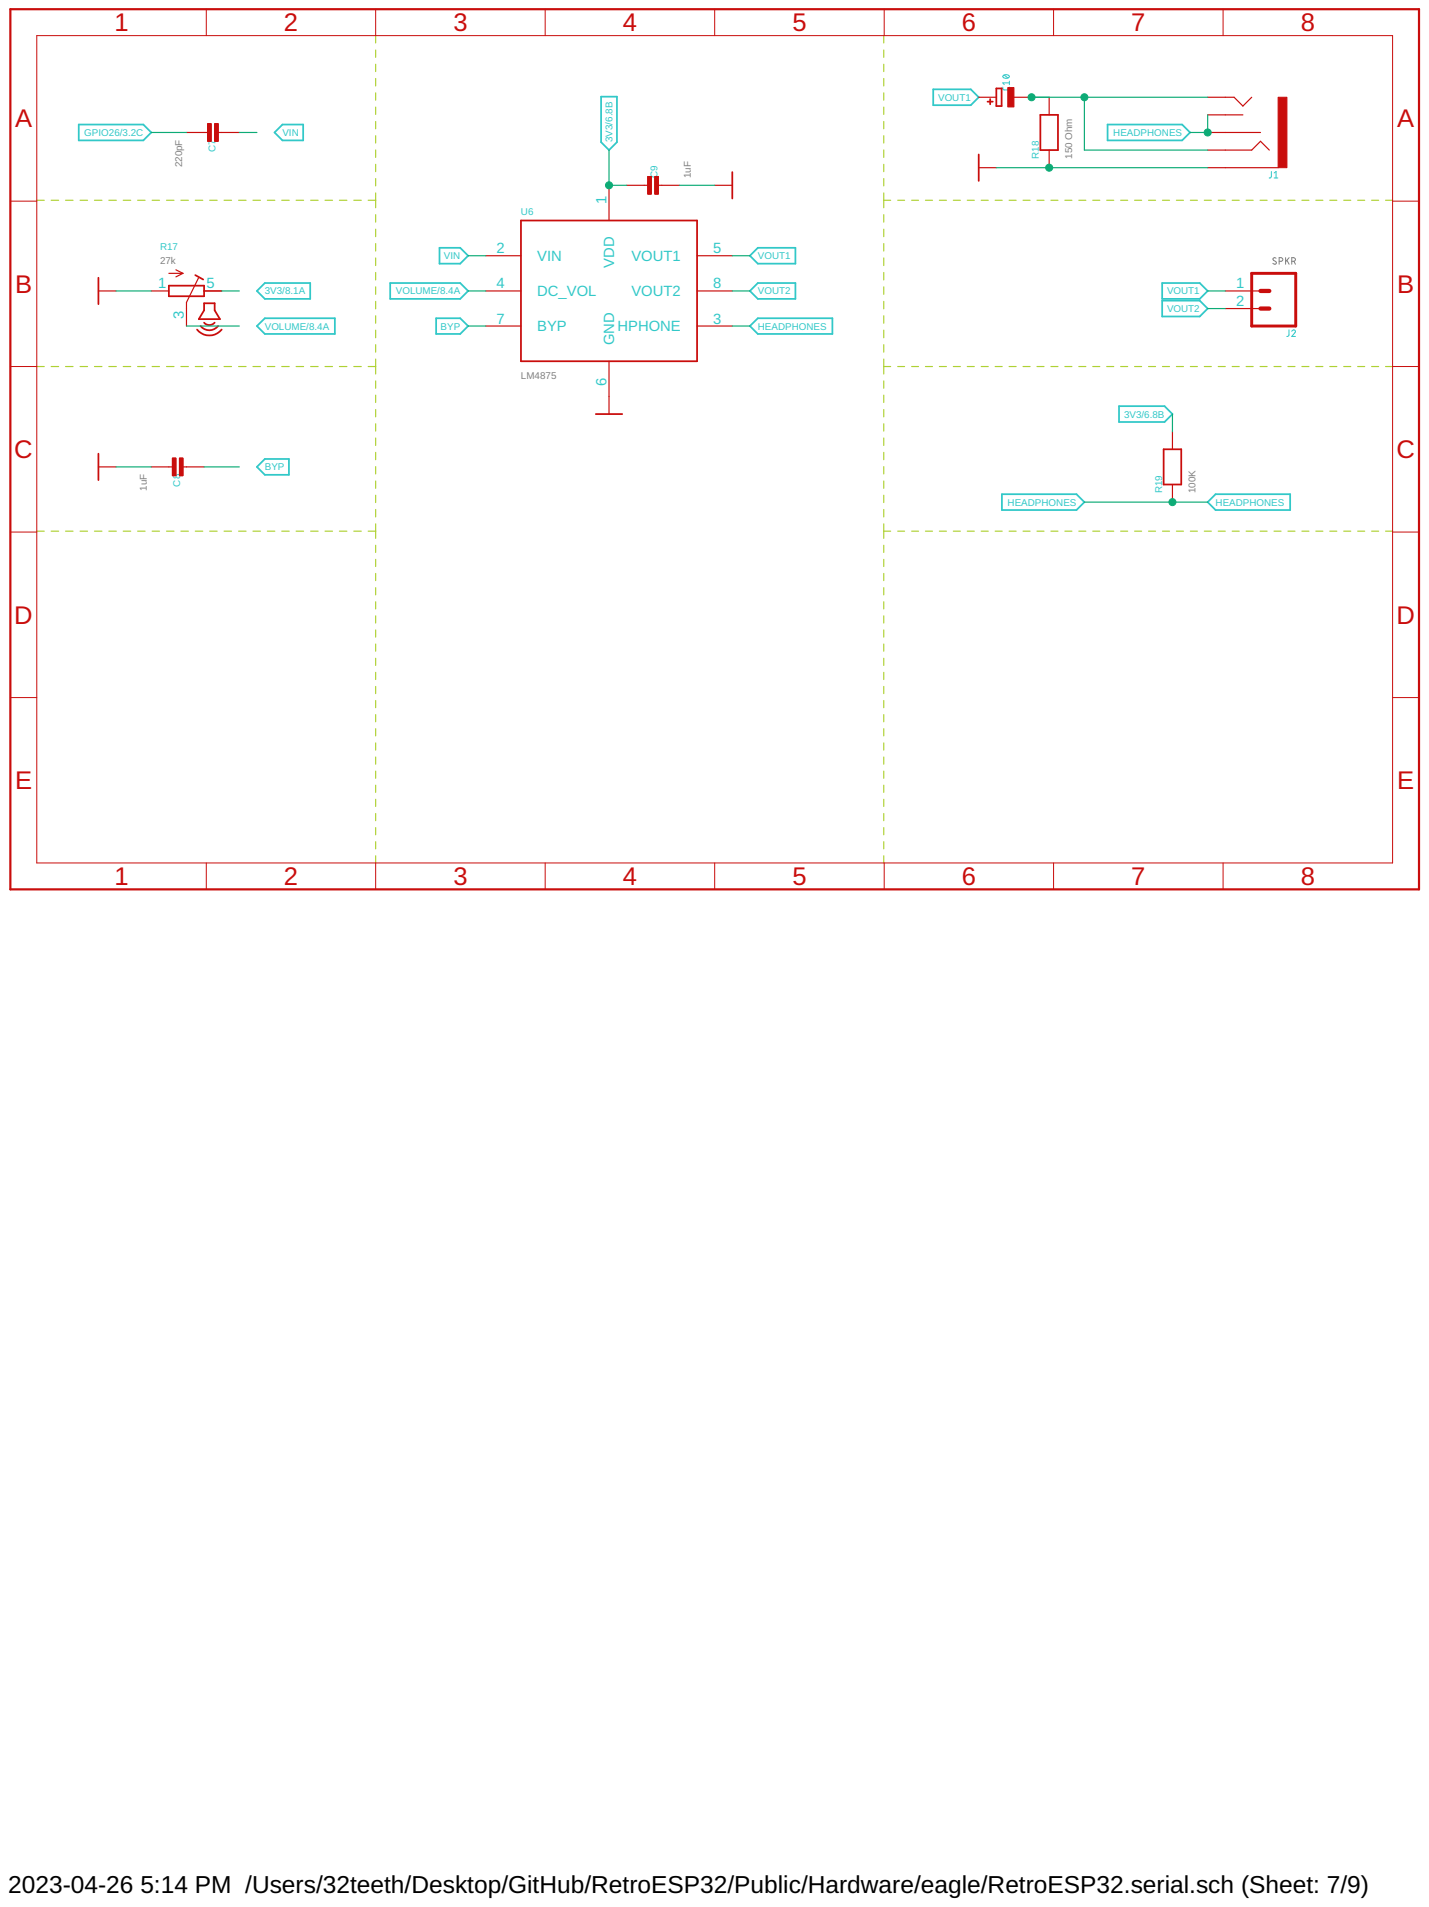
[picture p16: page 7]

2023-04-26 5:14 PM /Users/32teeth/Desktop/GitHub/RetroESP32/Public/Hardware/eagle/RetroESP32.serial.sch (Sheet: 7/9)

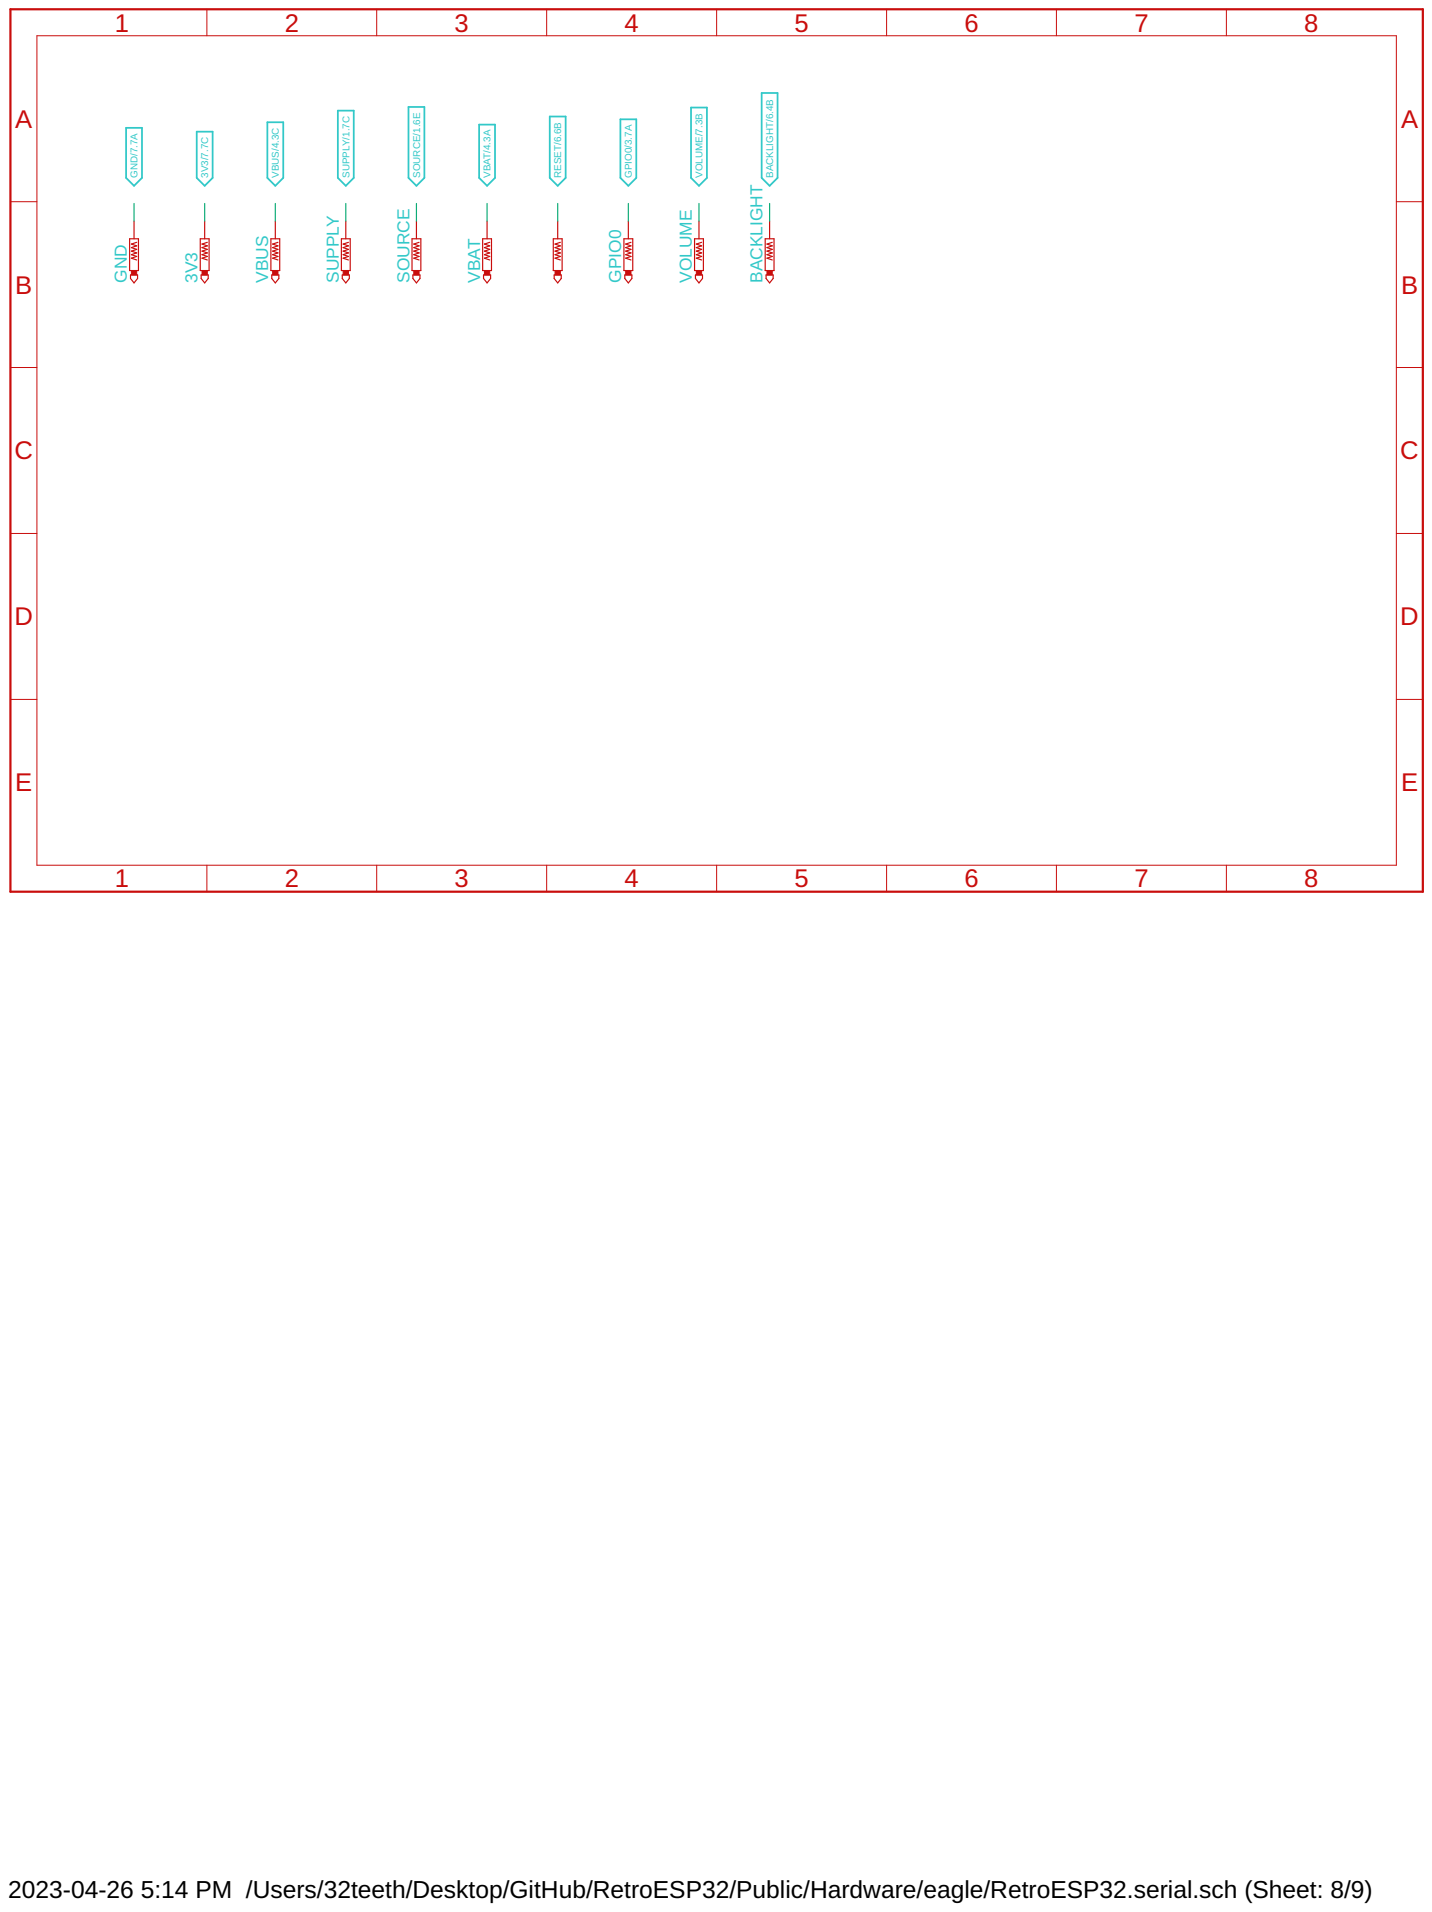
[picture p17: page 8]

2023-04-26 5:14 PM /Users/32teeth/Desktop/GitHub/RetroESP32/Public/Hardware/eagle/RetroESP32.serial.sch (Sheet: 8/9)

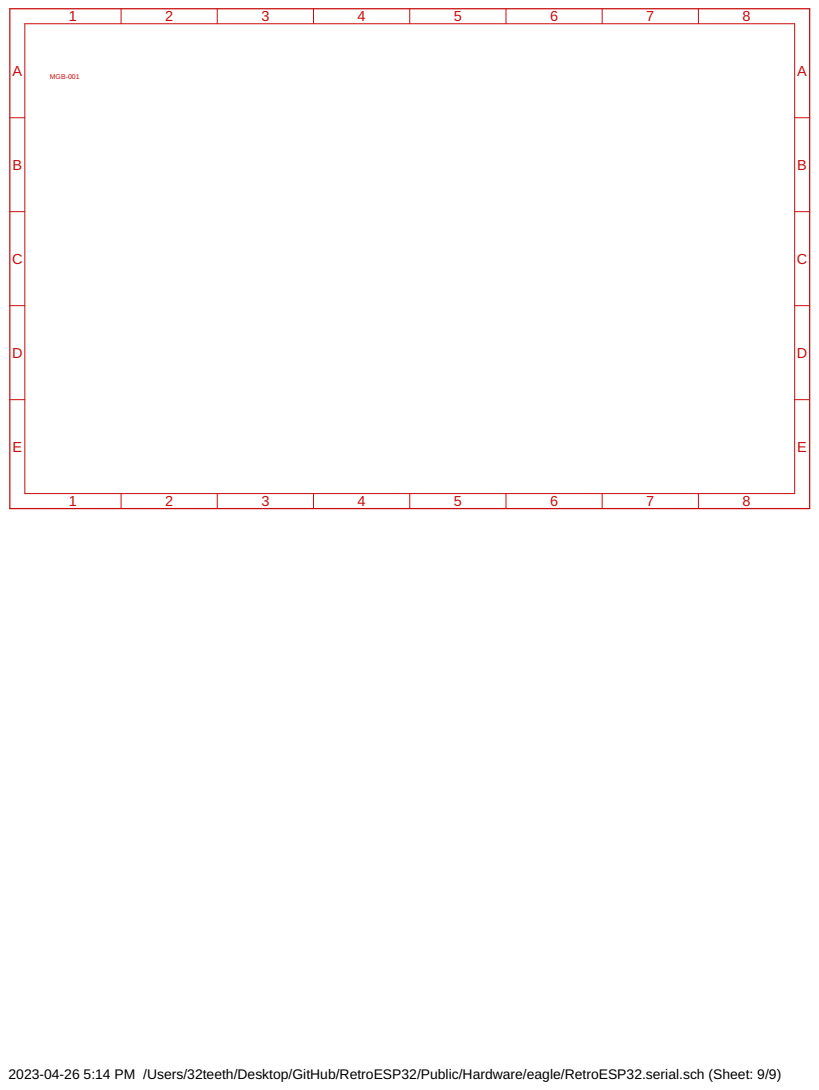
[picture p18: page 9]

2023-04-26 5:14 PM /Users/32teeth/Desktop/GitHub/RetroESP32/Public/Hardware/eagle/RetroESP32.serial.sch (Sheet: 9/9)

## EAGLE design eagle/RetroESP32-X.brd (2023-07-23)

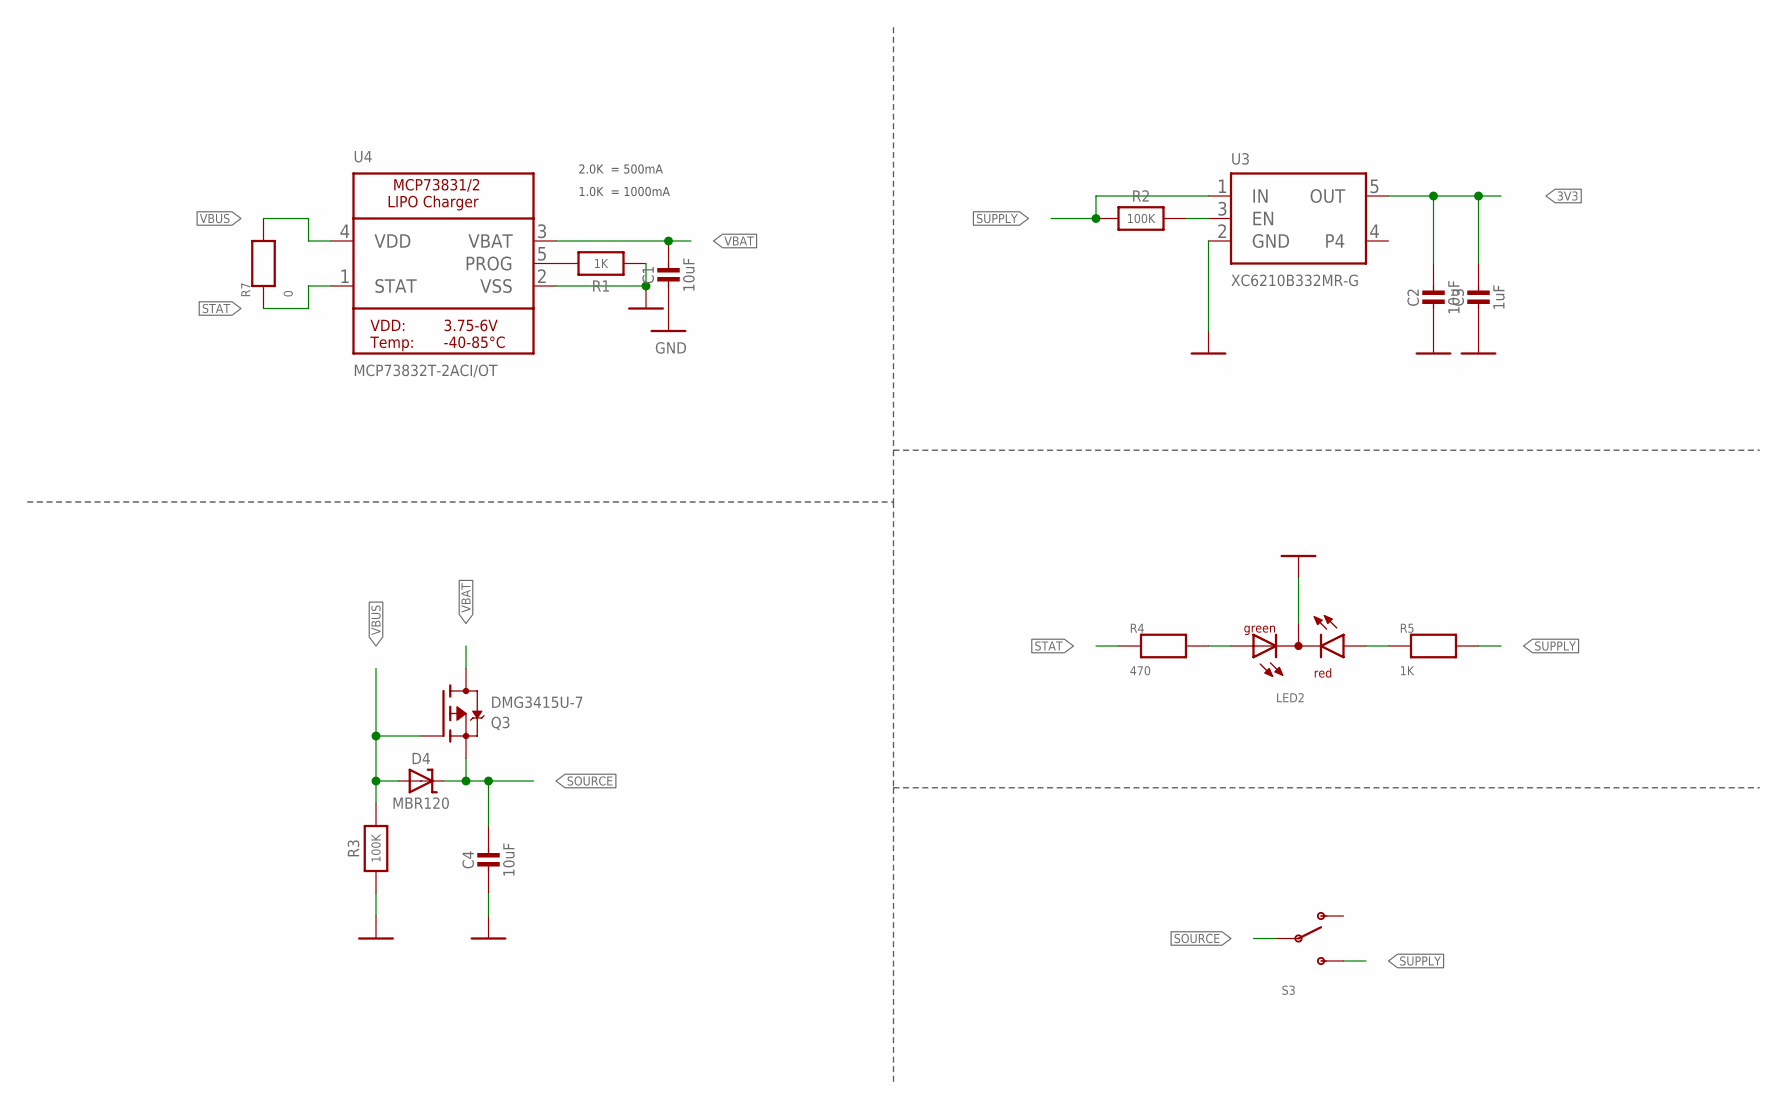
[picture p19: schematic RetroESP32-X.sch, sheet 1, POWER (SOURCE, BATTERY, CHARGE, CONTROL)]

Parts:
C1, C2, C4: 10uF; 0603-MINI-CAP; MPN CL10A106MP8NNNC
C3: 1uF; 0603-MINI-CAP; MPN CL10A105KP8NNNC
D4: MBR120; SOD-123; MPN MBR120LSFT1G
LED2: LED_L-115WEGW-CA; LED_DUOLED-A-3MM; MPN SSL-LX3059IGW
Q3: DMG3415U-7; SOT23-R; MPN DMG3415U-7
R1, R5: 1K; 0603-MINI; MPN ERJ-PA3J102V
R2, R3: 100K; 0603-MINI; MPN ERJ-PA3J104V
R4: 470; 0603-MINI; MPN ERJ-PA3J471V
R7: 0; 0603-MINI; MPN ERJ-3GEY0R00V
S3: POWER-SWITCH; RETIRED_KPS-1290; MPN MA12RTR
U3: XC6210B332MR-G; SOT23-5; MPN XC6210B332MR-G
U4: MCP73832T-2ACI/OT; SOT23-5-1; MPN MCP73832T-2ACI/OT

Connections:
3V3: C2.1, C3.1, U3.5 (OUT); also elsewhere on the board
EN: R2.2, U3.3 (EN)
GND: C1.2, C2.2, C3.2, C4.2, LED2.2 (A), R1.1, R3.1, U3.2 (GND), U4.2 (VSS); also elsewhere on the board
POWER_LED: LED2.3 (CR), R5.1
PROG: R1.2, U4.5 (PROG)
SOURCE: C4.1, D4.C, Q3.2 (S), S3.P
STAT: R4.1, R7.1, U4.1 (STAT)
STAT_LED: LED2.1 (CG), R4.2
SUPPLY: R2.1, R5.2, S3.S, U3.1 (IN)
VBAT: C1.1, Q3.3 (D), U4.3 (VBAT); also elsewhere on the board
VBUS: D4.A, Q3.1 (G), R3.2, R7.2, U4.4 (VDD); also elsewhere on the board

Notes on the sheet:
2.0K = 500mA
1.0K = 1000mA

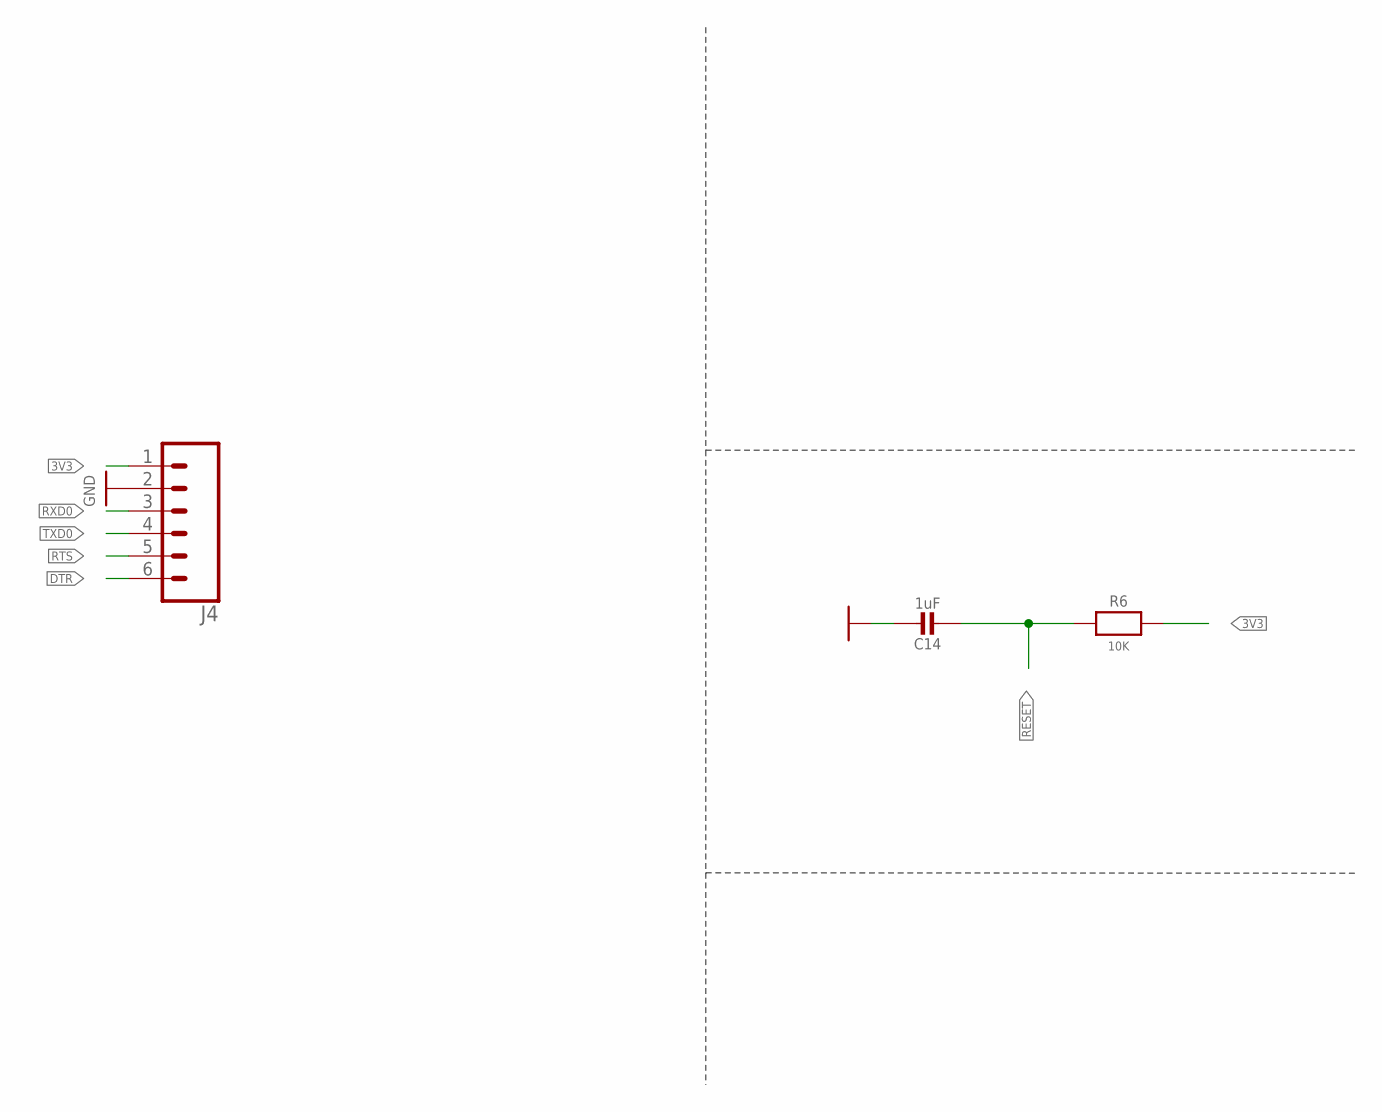
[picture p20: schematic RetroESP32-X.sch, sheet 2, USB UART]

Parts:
C14: 1uF; 0603-MINI-CAP; MPN CL10A105KP8NNNC
J4: CONN_06NO_SILK_NO_POP; 1X06_NO_SILK
R6: 10K; 0603-MINI; MPN ERJ-PA3J103V

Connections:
3V3: J4.1, R6.2; also elsewhere on the board
DTR: J4.6; also elsewhere on the board
GND: C14.1, J4.2; also elsewhere on the board
RESET: C14.2, R6.1; also elsewhere on the board
RTS: J4.5; also elsewhere on the board
RXD0: J4.3; also elsewhere on the board
TXD0: J4.4; also elsewhere on the board

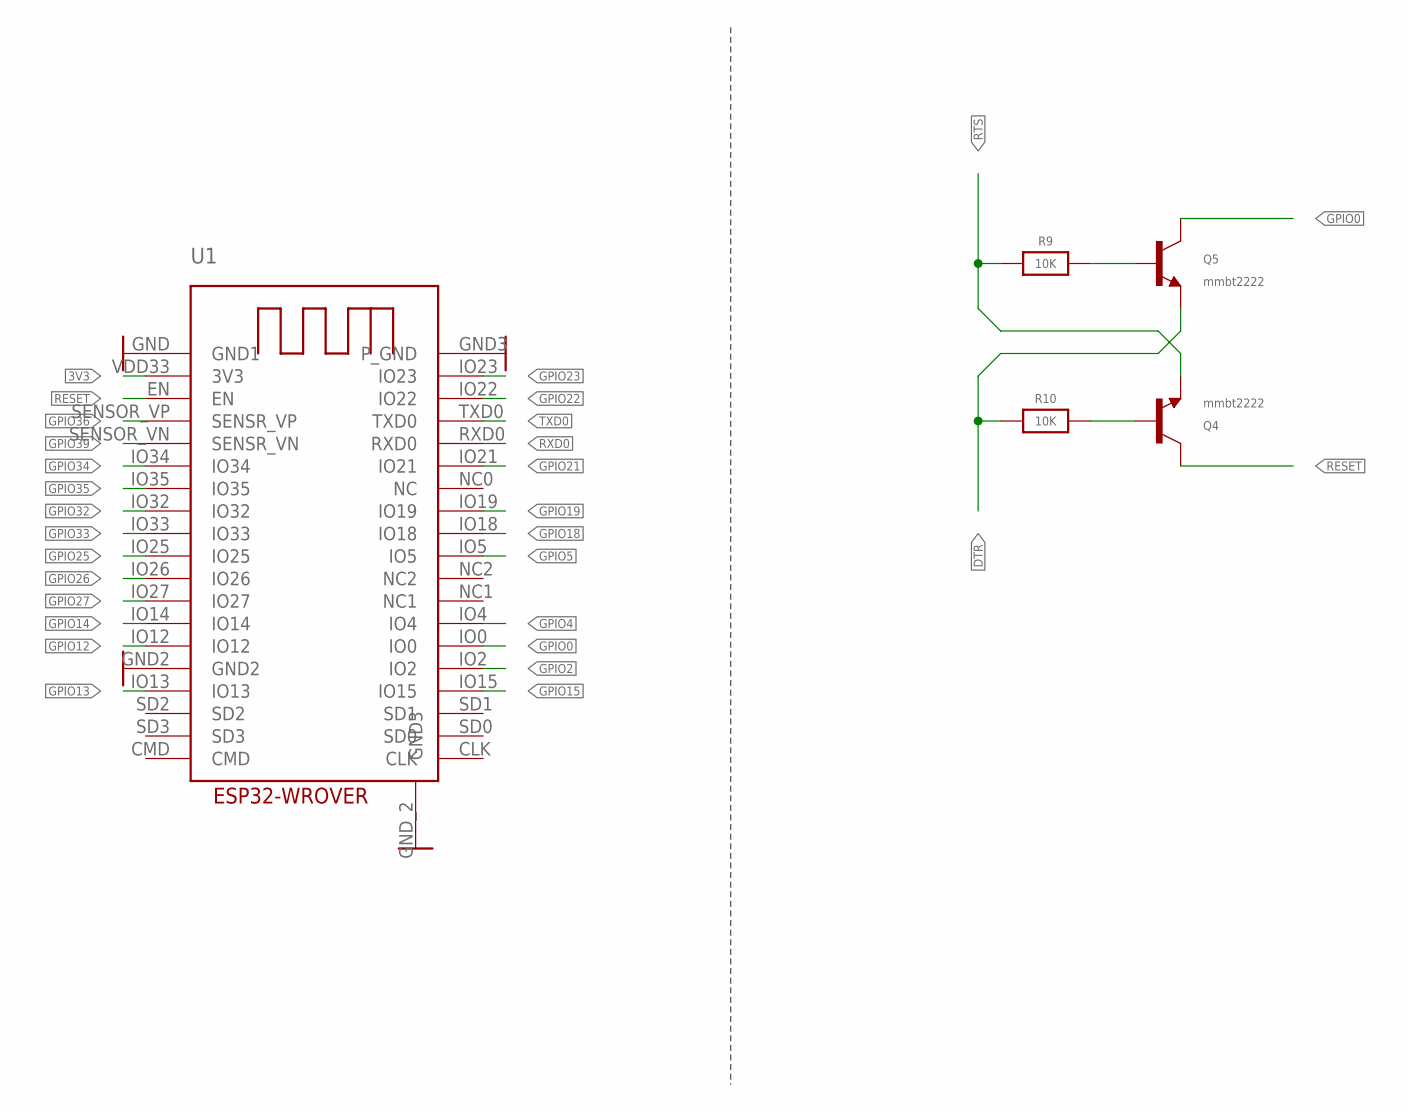
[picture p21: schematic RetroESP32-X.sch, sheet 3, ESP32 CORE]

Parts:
Q4, Q5: mmbt2222; SOT23-3; MPN MMBT2222A-7-F
R9, R10: 10K; 0603-MINI; MPN ERJ-PA3J103V
U1: ESP32-WROVER; ESP32-WROVER_ESP32-WROVER; MPN ESP32-WROVER (16MB)

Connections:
3V3: U1.VDD33 (3V3); also elsewhere on the board
DTR: Q5.2 (E), R10.1; also elsewhere on the board
GND: U1.GND (GND1), U1.GND2, U1.GND3 (P_GND), U1.GND_2 (GND3); also elsewhere on the board
GPIO0: Q5.3 (C), U1.IO0
GPIO2: U1.IO2
GPIO4: U1.IO4
GPIO5: U1.IO5; also elsewhere on the board
GPIO12: U1.IO12
GPIO13: U1.IO13
GPIO14: U1.IO14
GPIO15: U1.IO15
GPIO18: U1.IO18; also elsewhere on the board
GPIO19: U1.IO19; also elsewhere on the board
GPIO21: U1.IO21; also elsewhere on the board
GPIO22: U1.IO22; also elsewhere on the board
GPIO23: U1.IO23; also elsewhere on the board
GPIO25: U1.IO25
GPIO26: U1.IO26; also elsewhere on the board
GPIO27: U1.IO27; also elsewhere on the board
GPIO32: U1.IO32; also elsewhere on the board
GPIO33: U1.IO33; also elsewhere on the board
GPIO34: U1.IO34; also elsewhere on the board
GPIO35: U1.IO35; also elsewhere on the board
GPIO36: U1.SENSOR_VP (SENSR_VP); also elsewhere on the board
GPIO39: U1.SENSOR_VN (SENSR_VN); also elsewhere on the board
RESET: Q4.3 (C), U1.EN; also elsewhere on the board
RST-RES: Q4.1 (B), R10.2
RTS: Q4.2 (E), R9.1; also elsewhere on the board
RTS-RES: Q5.1 (B), R9.2
RXD0: U1.RXD0; also elsewhere on the board
TXD0: U1.TXD0; also elsewhere on the board

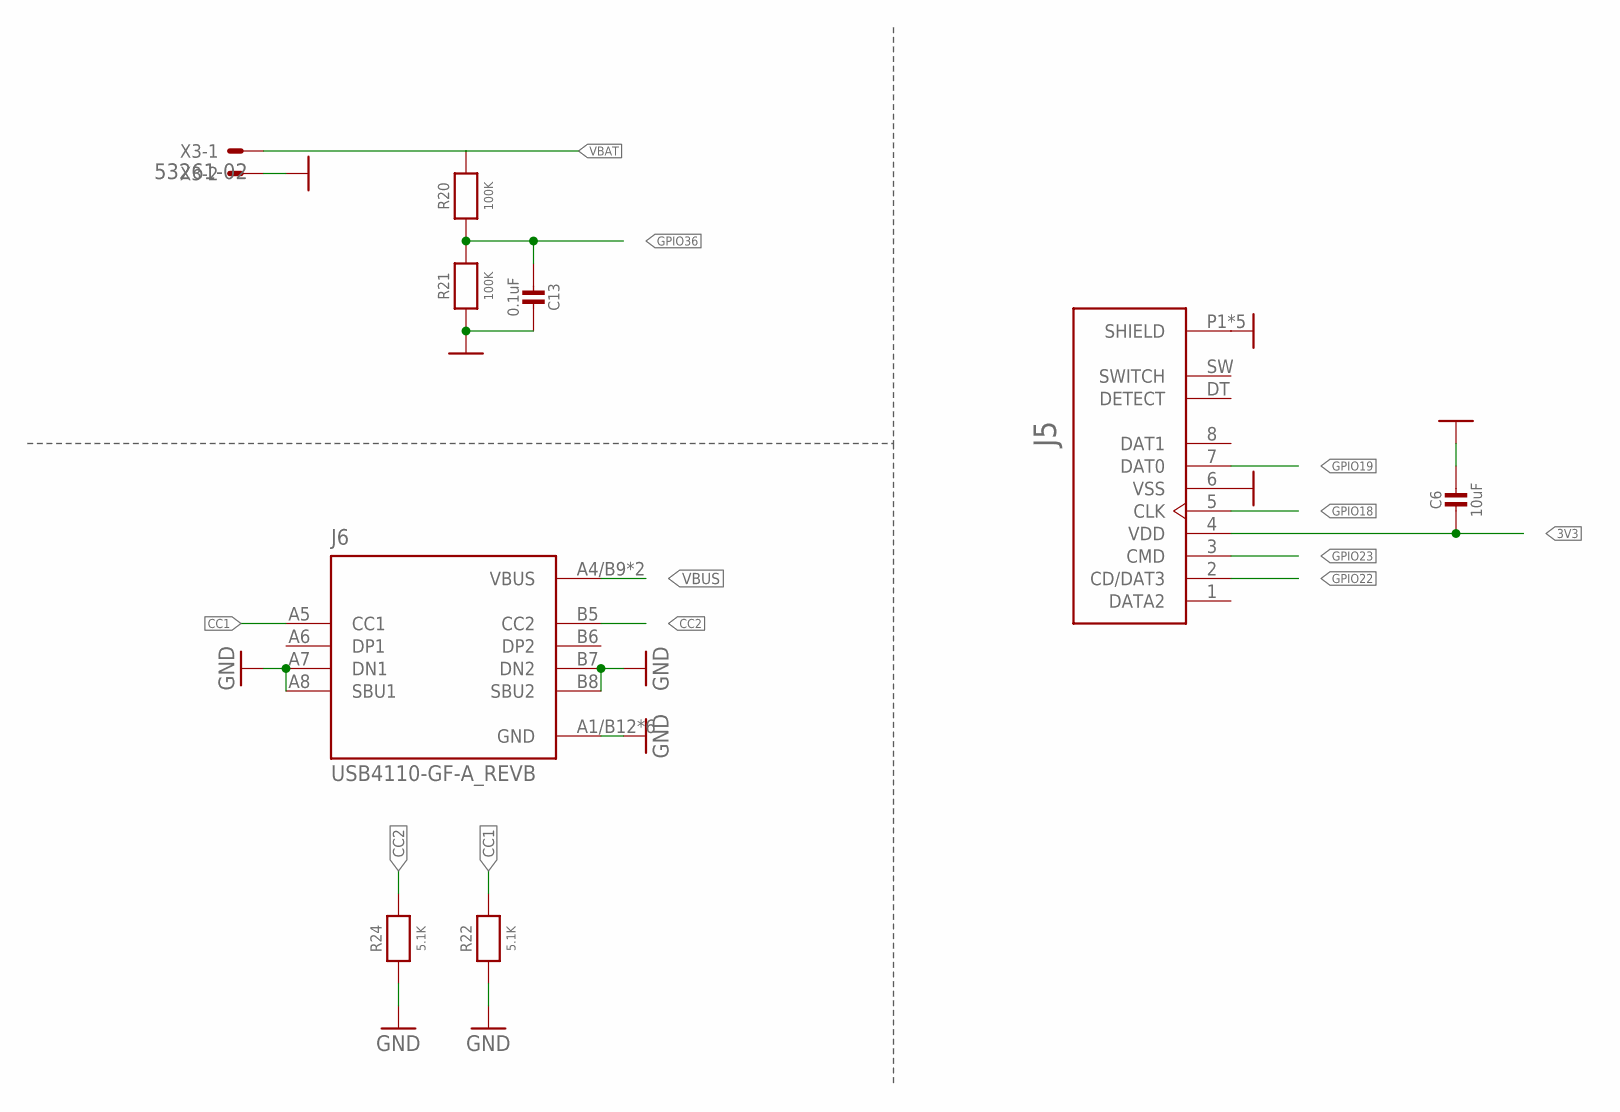
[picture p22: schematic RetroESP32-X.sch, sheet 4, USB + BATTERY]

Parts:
C6: 10uF; 0603-MINI-CAP; MPN CL10A106MP8NNNC
C13: 0.1uF; 0603-MINI-CAP; MPN CL10B104KB8NNNC
J5: 503182-1852_503182-1852; 503182-1852_MOLEX_503182-1852; MPN 5031821852
J6: USB4110-GF-A_REVB; GCT_USB4110-GF-A_REVB; MPN USB4105-GF-A
R20, R21: 100K; 0603-MINI; MPN ERJ-PA3J104V
R22, R24: 5.1K; 0603-MINI; MPN ERJ-PA3F5101V
X3: 53261-02; MPN 0532614002

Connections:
3V3: C6.2, J5.4 (VDD); also elsewhere on the board
CC1: J6.A5 (CC1), R22.2
CC2: J6.B5 (CC2), R24.2
GND: C6.1, C13.1, J5.6 (VSS), J5.P1 (SHIELD), J5.P2 (SHIELD), J5.P3 (SHIELD), J5.P4 (SHIELD), J5.P5 (SHIELD), J6.A1/B12 (GND), J6.A7 (DN1), J6.A8 (SBU1), J6.B1/A12 (GND), J6.B7 (DN2), J6.B8 (SBU2), J6.S1 (GND), J6.S2 (GND), J6.S3 (GND), J6.S4 (GND), R21.1, R22.1, R24.1, X3.2; also elsewhere on the board
GPIO18: J5.5 (CLK); also elsewhere on the board
GPIO19: J5.7 (DAT0); also elsewhere on the board
GPIO22: J5.2 (CD/DAT3); also elsewhere on the board
GPIO23: J5.3 (CMD); also elsewhere on the board
GPIO36: C13.2, R20.1, R21.2; also elsewhere on the board
VBAT: R20.2, X3.1; also elsewhere on the board
VBUS: J6.A4/B9 (VBUS), J6.B4/A9 (VBUS); also elsewhere on the board

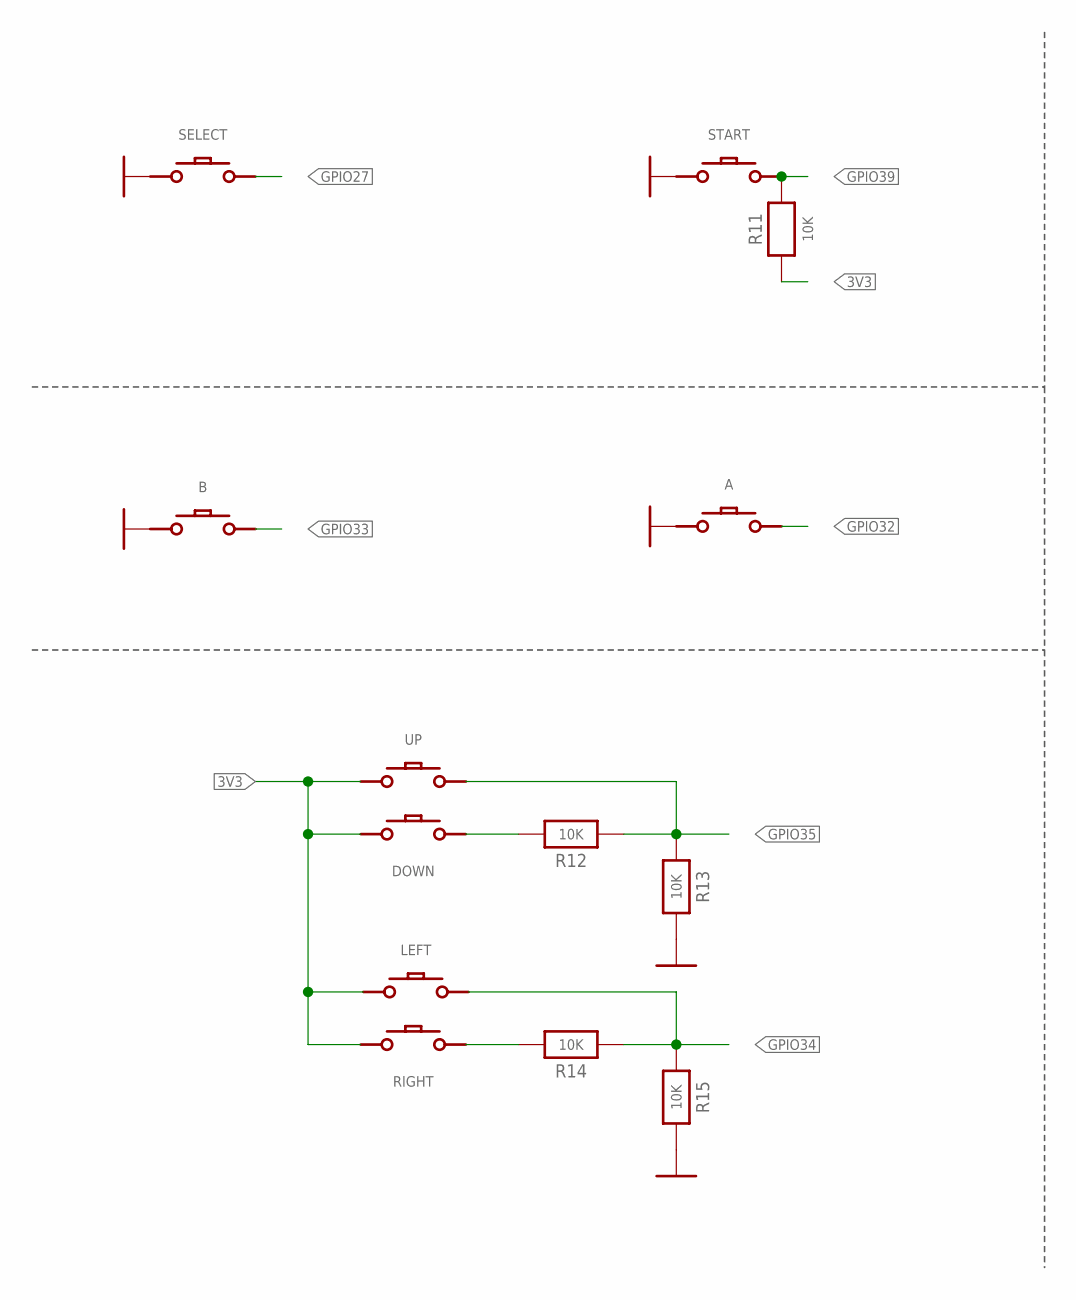
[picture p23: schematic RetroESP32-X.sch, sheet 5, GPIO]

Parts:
A: BUTTONSCONDUCTIVE_BUTTON_MGB; ACTION-GAMEBOY
B: BUTTONSCONDUCTIVE_BUTTON_MGB; ACTION-GAMEBOY
DOWN: BUTTONSCONDUCTIVE_BUTTON_DIRECTION_THIN; DIRECTIONAL-SPACED-PAD
LEFT: BUTTONSCONDUCTIVE_BUTTON_DIRECTION_THIN; DIRECTIONAL-SPACED-PAD
R11, R12, R13, R14, R15: 10K; 0603-MINI; MPN ERJ-PA3J103V
RIGHT: BUTTONSCONDUCTIVE_BUTTON_DIRECTION_THIN; DIRECTIONAL-SPACED-PAD
SELECT: BUTTON_START+SELECT; START+SELECT-STANDARD
START: BUTTON_START+SELECT; START+SELECT-STANDARD
UP: BUTTONSCONDUCTIVE_BUTTON_DIRECTION_THIN; DIRECTIONAL-SPACED-PAD

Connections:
3V3: DOWN.P$GND, LEFT.P$GND, R11.1, RIGHT.P$GND, UP.P$GND; also elsewhere on the board
DOWN: DOWN.P$ACTIVE, R12.2
GND: A.P$GND, A.P$GND1 (P$GND), B.P$GND, B.P$GND1 (P$GND), R13.2, R15.2, SELECT.P$GND, SELECT.P$GND1 (P$GND), SELECT.P$GND2 (P$GND), SELECT.P$GND3 (P$GND), START.P$GND, START.P$GND1 (P$GND), START.P$GND2 (P$GND), START.P$GND3 (P$GND); also elsewhere on the board
GPIO27: SELECT.P$ACTIVE, SELECT.P$ACTIVE1 (P$ACTIVE), SELECT.P$ACTIVE2 (P$ACTIVE), SELECT.P$ACTIVE3 (P$ACTIVE), SELECT.P$ACTIVE4 (P$ACTIVE), SELECT.P$ACTIVE5 (P$ACTIVE), SELECT.P$ACTIVE6 (P$ACTIVE); also elsewhere on the board
GPIO32: A.P$ACTIVE, A.P$ACTIVE1 (P$ACTIVE); also elsewhere on the board
GPIO33: B.P$ACTIVE, B.P$ACTIVE1 (P$ACTIVE); also elsewhere on the board
GPIO34: LEFT.P$ACTIVE, R14.1, R15.1; also elsewhere on the board
GPIO35: R12.1, R13.1, UP.P$ACTIVE; also elsewhere on the board
GPIO39: R11.2, START.P$ACTIVE, START.P$ACTIVE1 (P$ACTIVE), START.P$ACTIVE2 (P$ACTIVE), START.P$ACTIVE3 (P$ACTIVE), START.P$ACTIVE4 (P$ACTIVE), START.P$ACTIVE5 (P$ACTIVE), START.P$ACTIVE6 (P$ACTIVE); also elsewhere on the board
RIGHT: R14.2, RIGHT.P$ACTIVE

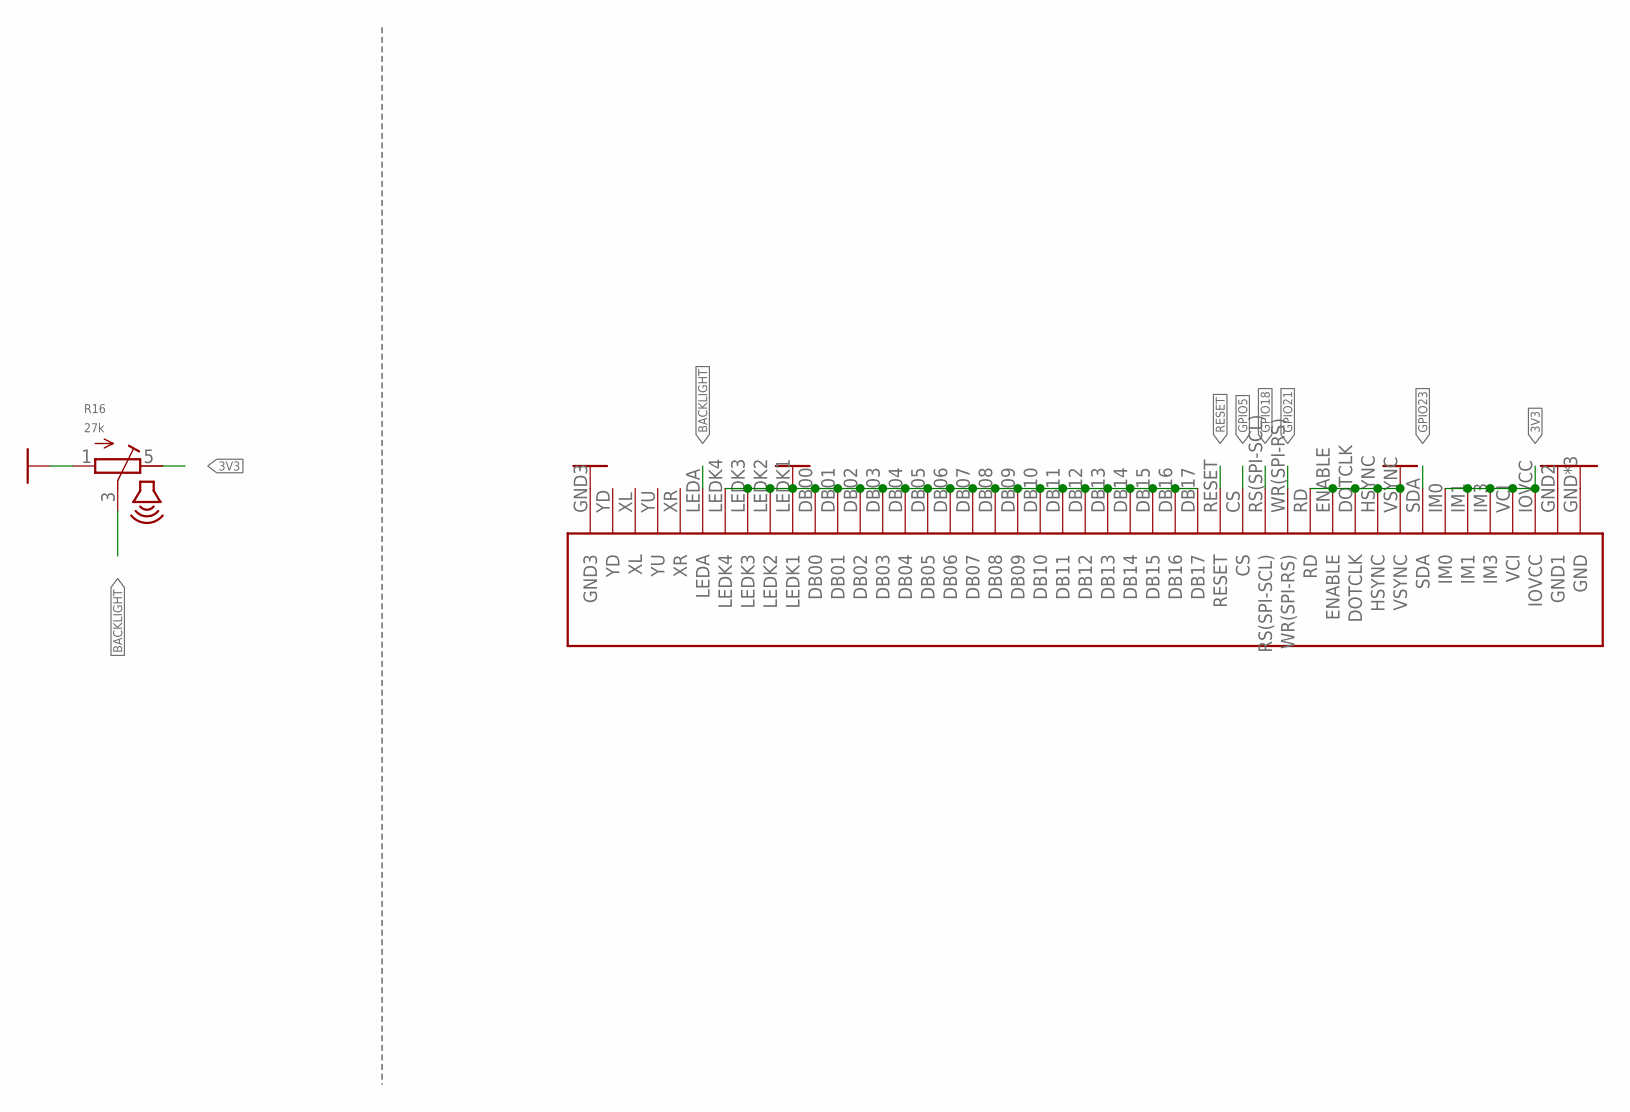
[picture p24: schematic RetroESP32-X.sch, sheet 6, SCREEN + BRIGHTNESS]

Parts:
R16: 27k; THUMBWHEEL
U$11: LCD-ILI9342CKD026LQTMA008=PASSTHRU-2023; KD026LQTMA008-PASSTHRU-2023; MPN 0541044531

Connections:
3V3: R16.5 (E), U$11.IM0, U$11.IM1, U$11.IM3, U$11.IOVCC, U$11.VCI; also elsewhere on the board
BACKLIGHT: R16.3 (S), U$11.LEDA
GND: R16.1 (A), U$11.DB00, U$11.DB01, U$11.DB02, U$11.DB03, U$11.DB04, U$11.DB05, U$11.DB06, U$11.DB07, U$11.DB08, U$11.DB09, U$11.DB10, U$11.DB11, U$11.DB12, U$11.DB13, U$11.DB14, U$11.DB15, U$11.DB16, U$11.DB17, U$11.DOTCLK, U$11.ENABLE, U$11.GND, U$11.GND2 (GND1), U$11.GND3, U$11.HSYNC, U$11.LEDK1, U$11.LEDK2, U$11.LEDK3, U$11.LEDK4, U$11.PAD$1 (GND), U$11.PAD$2 (GND), U$11.RD, U$11.VSYNC; also elsewhere on the board
GPIO5: U$11.CS; also elsewhere on the board
GPIO18: U$11.RS(SPI-SCL); also elsewhere on the board
GPIO21: U$11.WR(SPI-RS); also elsewhere on the board
GPIO23: U$11.SDA; also elsewhere on the board
RESET: U$11.RESET; also elsewhere on the board

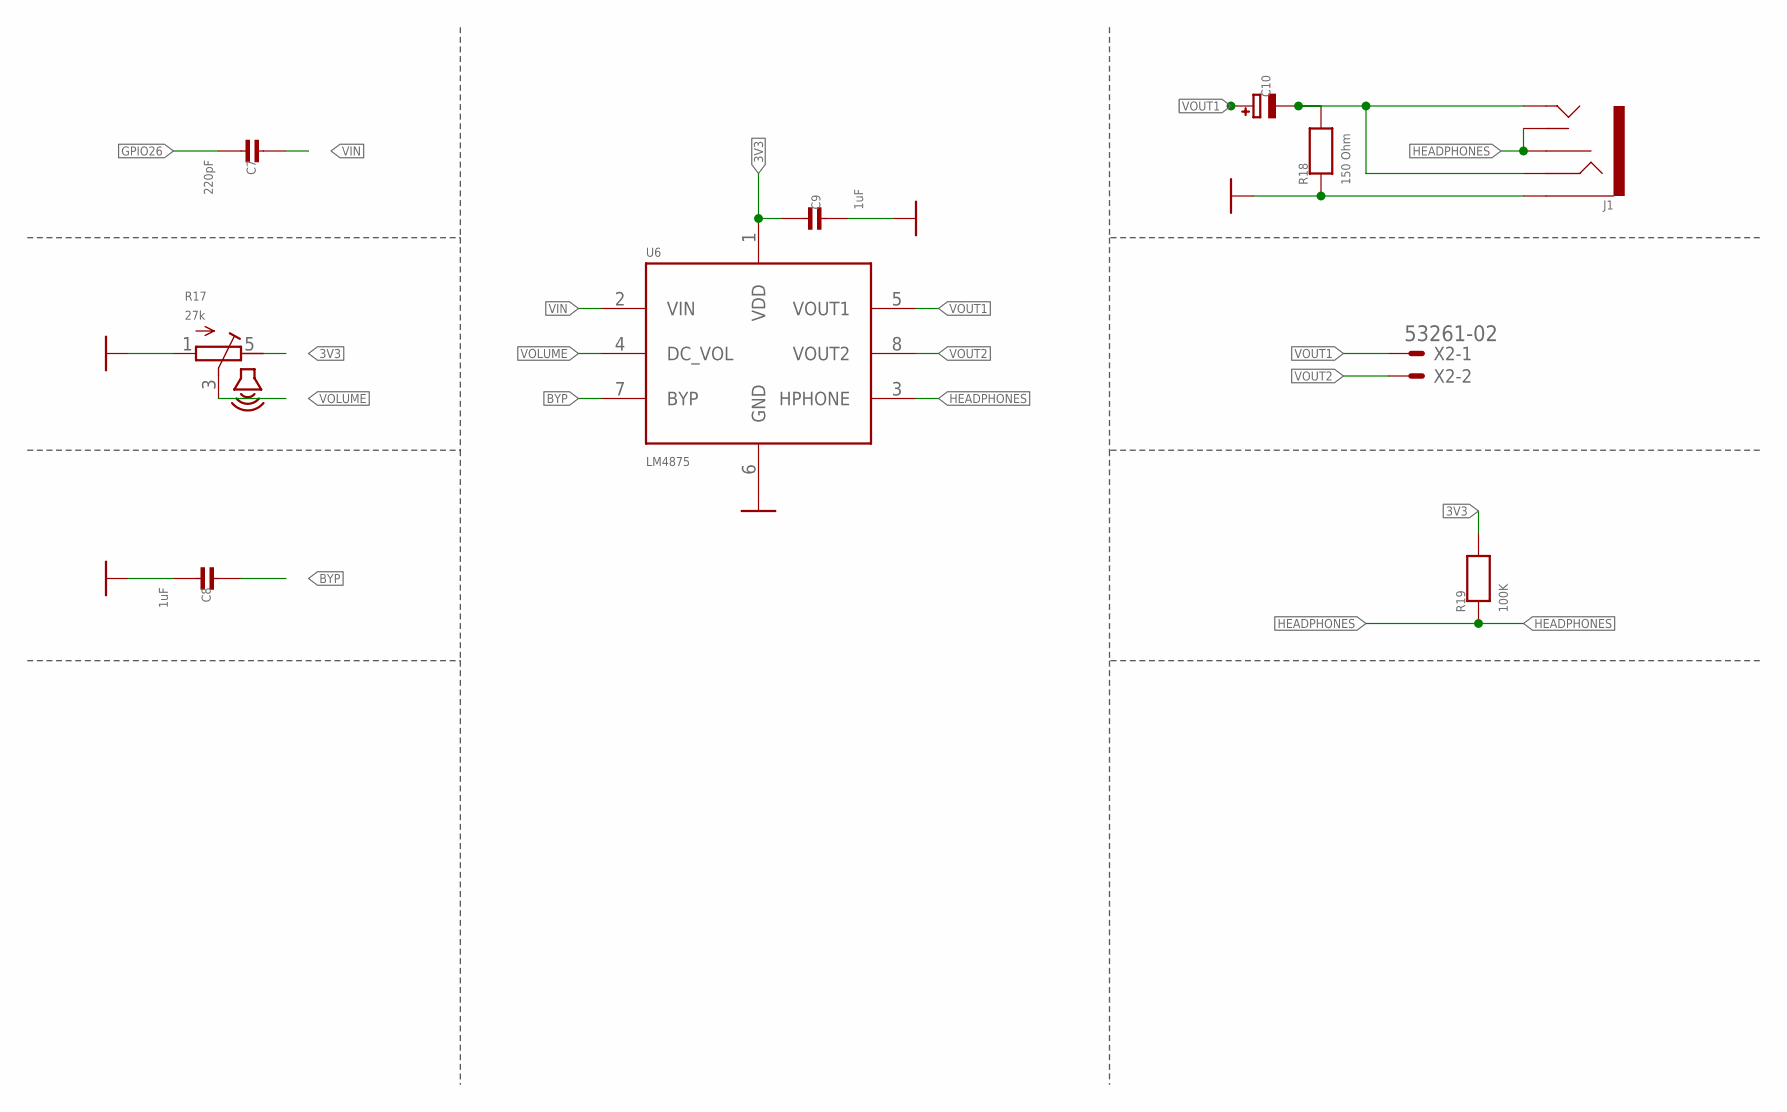
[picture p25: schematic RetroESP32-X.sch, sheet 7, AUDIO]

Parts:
C7: 220pF; 0603-MINI-CAP; MPN CL10C221JB8NNNC
C8, C9: 1uF; 0603-MINI-CAP; MPN CL10A105KP8NNNC
C10: 100uF; EIA3216-18/A-W; MPN F930J107KAA
J1: AUDIO_JACK_3.5MM_KIT; AUDIO-JACK-KIT; MPN SJ1-3525NG-GR
R17: 27k; THUMBWHEEL
R18: 150 Ohm; 0603-MINI; MPN ERJ-PA3J151V
R19: 100K; 0603-MINI; MPN ERJ-PA3J104V
U6: LM4875; SOIC8; MPN LM4875MX/NOPB
X2: 53261-02; MPN 0532614002

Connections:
3V3: C9.1, R17.5 (E), R19.2, U6.1 (VDD); also elsewhere on the board
BYP: C8.1, U6.7 (BYP)
GND: C8.2, C9.2, J1.SLEEVE, R17.1 (A), R18.1, U6.6 (GND); also elsewhere on the board
GPIO26: C7.2; also elsewhere on the board
HEADPHONES: J1.RSH, J1.TSH, R19.1, U6.3 (HPHONE)
VIN: C7.1, U6.2 (VIN)
VIN1: C10.-, J1.RING, J1.TIP, R18.2
VOLUME: R17.3 (S), U6.4 (DC_VOL)
VOUT1: C10.+, U6.5 (VOUT1), X2.1
VOUT2: U6.8 (VOUT2), X2.2

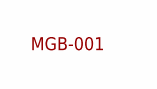
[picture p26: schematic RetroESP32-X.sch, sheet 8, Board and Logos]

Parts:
U$17: POCKET-BOARDSMGB-001-ESP32-2023; MGB-001-ESP32-2023

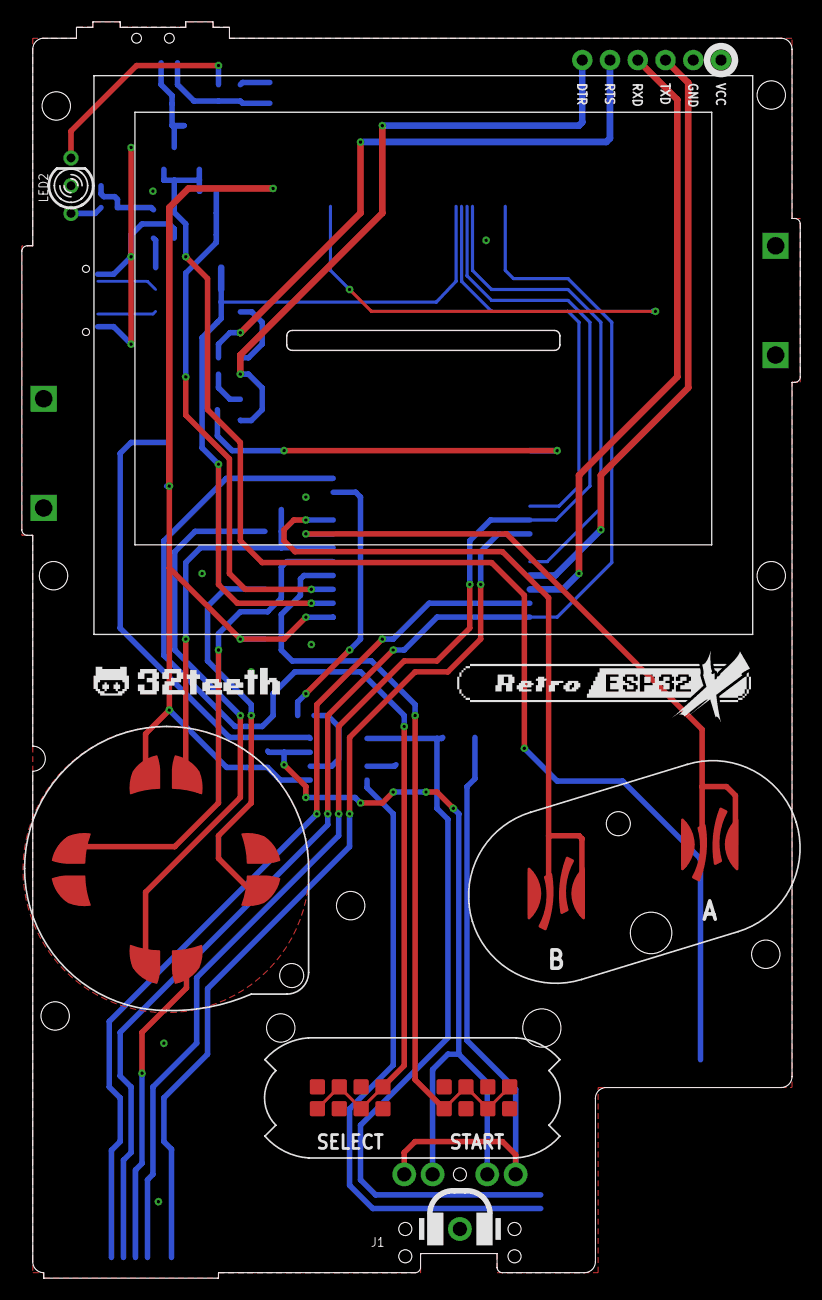
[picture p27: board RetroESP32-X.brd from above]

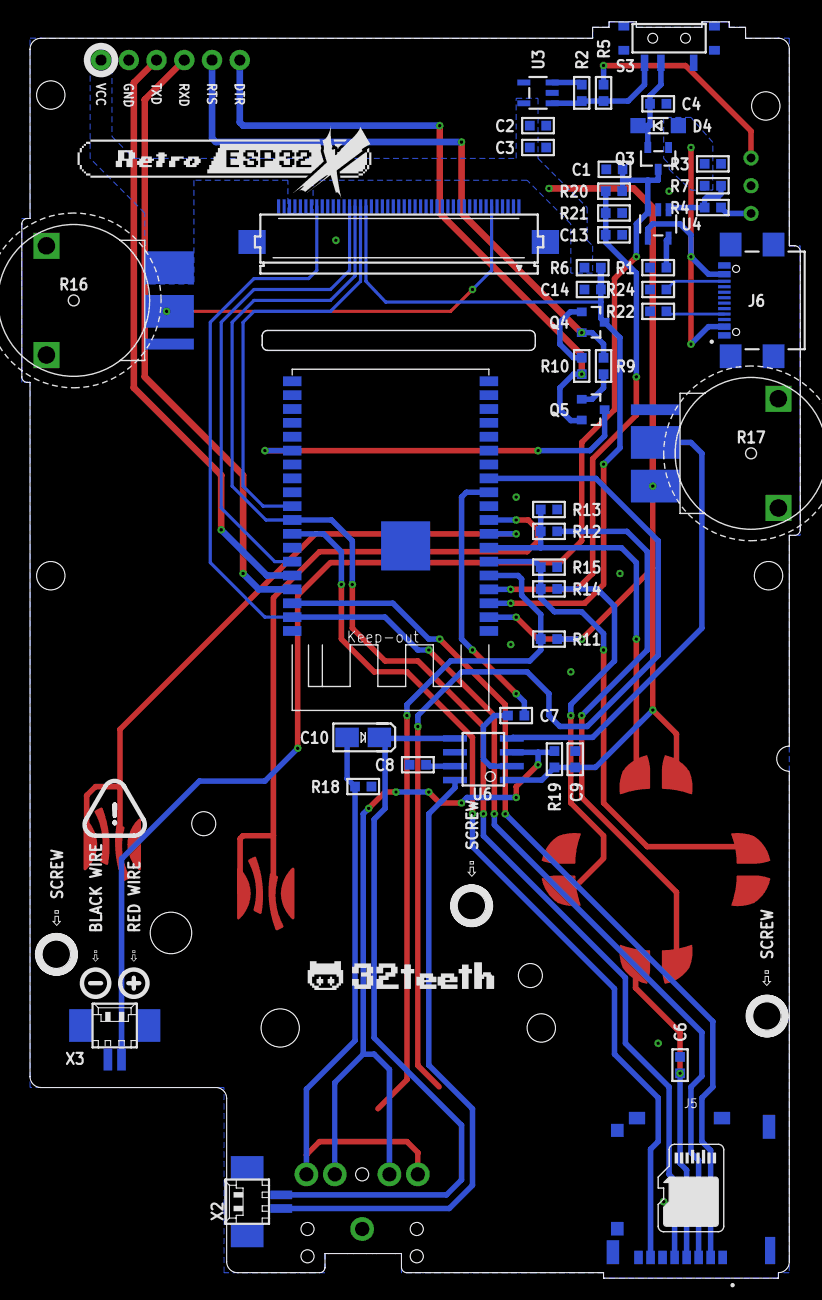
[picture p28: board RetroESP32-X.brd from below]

Board: 2 copper layers, 71.2 x 115.0 mm, 59 parts (46 on the bottom side), 45 nets.

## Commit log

2021-03-18 Thu 18 Mar 2021 09:27:54 EDT - Public Release
    [RetroESP32.serial.brd, RetroESP32.serial.csv, RetroESP32.serial.dxf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]
2022-02-25 updated CC1/2 pins
    [RetroESP32.serial.brd, RetroESP32.serial.csv, RetroESP32.serial.sch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]
2022-02-27 Added new DXF and BOM
    [RetroESP32.serial.brd, RetroESP32.serial.csv, RetroESP32.serial.dxf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]
2022-03-11 added resistors to USB
    [RetroESP32.serial.GBL, RetroESP32.serial.GBO, RetroESP32.serial.GBP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]
2022-11-23 updated BOM
    [RetroESP32.serial.GBL, RetroESP32.serial.GBO, RetroESP32.serial.GBP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]
2023-02-08 added potentiometer part number
    [RetroESP32.serial.csv]
2023-03-28 chore: pre indiegogo commit
    [RetroESP32.serial.brd, RetroESP32.serial.csv, RetroESP32.serial.sch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]
2023-04-25 feat: new button library
    [RetroESP32.serial.brd, RetroESP32.serial.dxf, RetroESP32.serial.sch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]
2023-04-26 feat: new A/B buttons, osh gerber
    [RetroESP32.serial.brd, RetroESP32.serial.sch]
2023-04-26 feat: new A/B buttons, osh gerber, pdf schema
    [RetroESP32.serial 2.dxf, RetroESP32.serial.brd, RetroESP32.serial.sch]
2023-05-17 fix: restore brd files
    [RetroESP32.serial.brd]
2023-06-27 feat: update gerbers
    [RetroESP32.serial.brd, RetroESP32.serial.sch]
2023-06-27 feat: updated U$11 component
    [RetroESP32.serial.brd]
2023-06-27 feat: updated gerbers
2023-06-29 feat: updated shim
    [RetroESP32.serial.brd, RetroESP32.shim.brd]
2023-07-02 feat: new layout
    [RetroESP32.serial.brd, RetroESP32.serial.sch, RetroESP32.shim.brd]
2023-07-10 feat: replaced JST with molex connector
    [RetroESP32.serial.brd, RetroESP32.serial.csv, RetroESP32.serial.sch]
2023-07-10 feat: tighter d-pad
    [RetroESP32.serial.brd]
2023-07-10 feat: new splash
    [RetroESP32.shim.sch]
2023-07-23 feat: released X
    [RetroESP32-X.csv, RetroESP32.serial.brd, RetroESP32.serial.sch]
2023-08-01 feat: new board with passthrough lcd
    [RetroESP32-X.brd, RetroESP32-X.csv]
2023-08-12 feature: updated BOM for X
    [RetroESP32-X.csv]
2023-10-06 update: BOM for X
    [RetroESP32-X.clean.csv, RetroESP32.serial.brd, RetroESP32.serial.sch]
2023-10-29 Update: Tindie markdown update
    [RetroESP32-X.brd]

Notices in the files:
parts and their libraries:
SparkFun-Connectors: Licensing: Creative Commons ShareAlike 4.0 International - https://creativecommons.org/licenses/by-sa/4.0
